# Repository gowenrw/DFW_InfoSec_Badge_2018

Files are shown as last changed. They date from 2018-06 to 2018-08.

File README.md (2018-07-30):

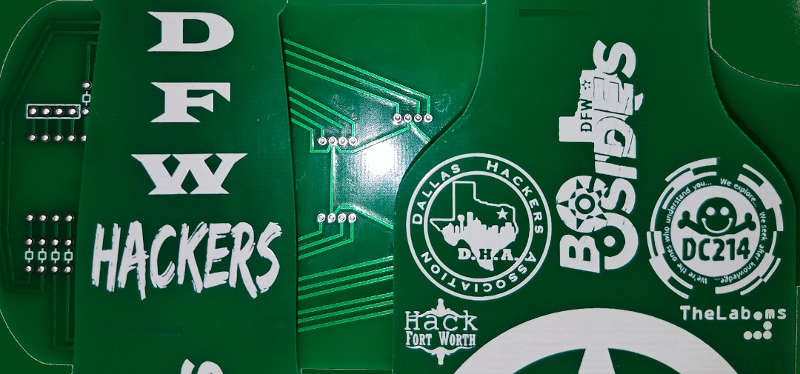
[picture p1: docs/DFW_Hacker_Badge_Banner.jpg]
Hero Image


# DFW Hacker Badge

Welcome to the DFW Hacker Badge website.

This is where you will find all the details of our badge including the components in the kit, assembly instructions, and code.

Please allow me to be your guide.

-- [@alt_bier](https://twitter.com/alt_bier)

## DIY Badge... Say What?!?

Yes, you read it correctly.  This is a DIY badge.  Some assembly required.
We will not be selling assembled badges.

This badge was designed to be an educational badge.

Building the badge from our kit will help teach people basic Electronics and Soldering skills
as well as Arduino Hardware Development and Programming skills.

To assist those without these skills I will link to online training that I created later on this page.
I will also be doing in person badge building classes at the following locations:

* A local DFW area badge building class will be scheduled in mid July.
    * This class has been scheduled for Tuesday July 17th at 6:30PM.
    * Sign up for the class via this Meetup link: [DFW Hacker Badge Building](https://www.meetup.com/TheLab-ms/events/252229891/)
* At BSidesLV I will find a nice corner to hang out and sell badges and answer any questions
    * I will post here and to twitter where and when that is once I know.
* At DEFCON I will be in the Hardware Hacking Village to sell badges and give building assistance
    * I'll post here and to twitter when I'll be at the HHV once my schedule is sorted.
* At BSidesDFW in Nov I will be running the Hardware Hacking Village featuring badge building.
    * This will be a much more comprehensive set of classes covering PCB design through badge assembly.
    * Details will be posted to BSidesDFW communications closer to that event.

## Show Me The Money!

All funds raised by the sale of this badge after production costs will go to
[BSidesDFW](http://www.bsidesdfw.com/) which is a 501c3 non-profit.

These badges will be sold at [BSidesLV](https://www.bsideslv.org/) and [DEFCON](https://defcon.org/).

The full kit will cost **$40.00** and just the PCB with no components will cost **$20.00** .

Early bird adopters (DFW area sales prior to hacker summer camp) will get them for half off.

A complete financial overview of the project including production costs is stored in this repo
and is available [HERE](https://github.com/gowenrw/DFW_InfoSec_Badge_2018/blob/master/Financials.md) for review.

## What's In The Kit?

The badge kit will contain everything you see pictured below.

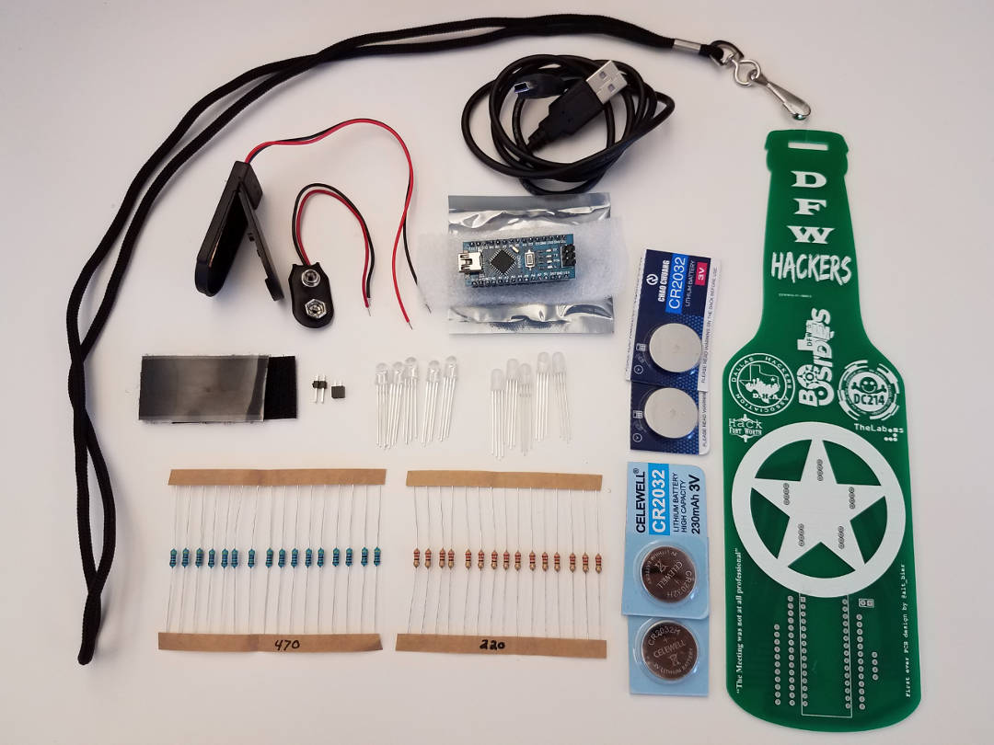
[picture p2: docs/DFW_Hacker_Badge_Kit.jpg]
Badge Kit Image


Here is a complete list of the items included in the kit:

* 1x Beer Bottle Shaped PCB
* 1x Lanyard (black or green)
* 1x Arduino Nano (pre-loaded with badge code)
* 1x USB A to Mini-B Cable (for programming the Arduino)
* 5x RGB LEDs 5mm 4pin diffused (recommended LEDs)
* 5x RGB LEDs 5mm 4pin clear (optional LEDs to replace above for clear aesthetic)
* 15x 470 ohm resistors (recommended resistors)
* 15x 220 ohm resistors (optional to replace above for brighter LEDs and shorter battery life)
* 1x 1x2 male header pins (optional use for power pins)
* 1x 1x2 female header pins (optional use for power pins)
* 1x 6v 2xCR2032 coin cell battery holder (recommended battery holder)
* 4x CR2032 coin cell batteries (two sets for above)
* 1x 9v battery holder (optional replacement for above, 9v battery not included)
* 1 inch of Velcro adhesive strips (for battery holder attachment)

## Assembly Instructions

__[Click Here for detailed assembly instructions with pictures](./assembly.html)__

Here is a basic list of what you need to do:

* Add the Arduino to the PCB
    * Plug the Arduino into the front of the PCB by pushing its header pins into the appropriate holes
    * It should be a tight fit but make sure the Arduino is pushed all the way down
    * Flip the PCB over so that the header pins poking through are clearly visible
    * Solder each pin to the pad surrounding the hole on the PCB
    * Inspect each solder joint and correct as needed
    * On the backside of the PCB cut the header pins off just above the solder joint
* Add the resistors to the PCB
    * Unlike the header pins on the Arduino, the resistors have soft leads that are easy to bend
    * Bend each resistor into a U shape (with the resistor at the bottom of the U)
    * Push each resistors leads into appropriate holes in the front of the PCB
    * This will be a very loose fit so take care to hold the resistor in place as you flip the PCB over
    * On the back of the PCB bend the leads outward at 45 to 90 degrees to hold the resistor in place
    * Solder each lead of the resistor to the pad surrounding the hole on the PCB
    * Inspect each solder joint and correct as needed
    * On the backside of the PCB cut the leads off just above the solder joint
* Add the LEDs to the PCB
    * Plug each LED into the front of the PCB by pushing its header pins into the appropriate holes
    * Make sure you orient the LED correctly so the common cathode pin goes into the correct hole.
        * Each LED will have one pin longer than the others, this is the common cathode pin
        * You can tell the common cathode hole on the PCB by looking at the traces on the back
        * The common cathode holes for all five LEDs will be connected together by traces
    * It'll be a tight fit but make sure the LED is pushed all the way down to the pin stops
    * Flip the PCB over so that the LED pins poking through are clearly visible
    * Solder each pin to the pad surrounding the hole on the PCB
    * Inspect each solder joint and correct as needed
    * On the backside of the PCB cut the pins off just above the solder joint
* Add the battery connector to the PCB
    * Plug the bare ends of the lead wires for the battery connector into the power holes in the PCB
    * Secure the wires in place so that the bare wires do not move in the PCB holes
    * Solder each wire to the pad surrounding the hole on the PCB
    * Inspect each solder joint and correct as needed
    * Cut any excess wire off just beyond the solder joint
* Insert batteries and Turn it On     

If you are new to soldering you should review this training material I put together:
[Electronics Soldering Basics](http://solder.altbier.us/)

## Arduino Code for the Badge

The Arduino that came in the kit should have been loaded with code that will work with your badge.
This code walks different colors around the star of the badge by turning on and off LEDs.

This code is available here:
[DFW-InfoSec-Badge-Color_Walk_low_power](https://raw.githubusercontent.com/gowenrw/DFW_InfoSec_Badge_2018/master/DFW-InfoSec-Badge-Color_Walk_low_power/DFW-InfoSec-Badge-Color_Walk_low_power.ino)

There is a version of this code that lights multiple LEDs at once when walking color around the badge.
This version uses more power which is why it was not loaded by default.

This code is available here:
[DFW-InfoSec-Badge-Color_Walk](https://raw.githubusercontent.com/gowenrw/DFW_InfoSec_Badge_2018/master/DFW-InfoSec-Badge-Color_Walk/DFW-InfoSec-Badge-Color_Walk.ino)

There are more code examples in the github repository that you may want to check out.

If you are new to the Arduino you should review this training material I put together:
[Arduino for Beginners](http://arduino.altbier.us/)

---

# Badge Details

## Story

For a couple of years now several of us at the various DFW InfoSec groups have
talked about creating a badge to wear and trade at the cons.

However, it always seemed to hit the back burner until it was too late to get made in time.

This year was no different.  But, I really didn't want to let it go this time.

So, with no PCB creation experience and severe time limitation I set out on the quest for the badge.

## Timeline and Simplicity

I figured in order to make the timeline I would have to keep the board simple.

Given my lack of PCB experience, I decided to fall back on my hardware development board experience.

This allowed for the creation of a board that is just traces, pads, holes, and silkscreen art... simple.

All the components which include an Arduino Nano with some RGB LEDs will need to be added in post.

## Fritzing PCB Design

I decided to use Fritzing for the PCB design since I previously used its breadboard and
schematic features when working with various hardware development platforms.

While I realize that it is not the most robust program for working with PCBs, it does
support exporting Gerber files for manufacturing.

So, my prior knowledge and the timeline dictated its use over learning a new tool.

## Custom PCB Board Shape and Silkscreen

In order to make a custom shaped PCB with silkscreen art Fritzing requires vector graphics in SVG format.  
The SVG needs two group ID's, one for the board shape and one for the silkscreen art.
Here are what those look like:
```
<g id="board">
...
<g id="silkscreen">
```

So, I created an Illustrator image with these vectors and exported it to SVG.

Then I created a PCB in Fritzing and loaded the SVG image.
This is where I ran into a problem.  Fritzing requires width and height be specified.
This is regardless of any viewBox that may be present.
Illustrator exports with a viewBox only, so I needed to manually add the width and height
matching the viewBox values.

Here is what this looks like after my edit:
```
<svg version="1.2" baseProfile="tiny" xmlns="http://www.w3.org/2000/svg"
xmlns:xlink="http://www.w3.org/1999/xlink" x="0px"  y="0px"
width="248" height="832" viewBox="0 0 248 832" xml:space="preserve">
```

## The Circuit

I knew that I wanted to use an Arduino and some LEDs to keep it simple.
So, I came up with a design using an Arduino Nano and five RGB LEDs.

The trick to creating the circuit on the PCB was that I wanted to keep
the board to a single copper layer.
This means that no two traces can cross paths.

This did add some limitations to my design specifically in potential LED placement
as well as in the use of digital and analog pins.

But, these all worked out and I was able to create a circuit design that will
work as a single layer on a PCB.

## Testing The Circuit

Once I had the circuit designed I needed to make sure it would work.

So, I pulled out the boxes of breadboards, jumpers, and components.

I build the circuit exactly the way it was laid out on Fritzing.

I then wrote a quick Arduino script to test all five RGB LED functionality via the circuit.

It's some simple sloppy code, but got the job done... the circuit works.

##### Code Limitation

Because of the specific pins I had to use to each LED in order to keep it single layer, one
of the limitations is that most the LEDs do not have all three colors on analog or pwm pins.

These are the pins that allow you to do ```analogWrite``` to fade an LED on or off.

Since only ```digitalWrite``` will need to be used for consistency this means the RGB LED colors will be
on or off when they are set to ```HIGH``` or ```LOW``` and cannot be faded.
So, where you can turn on red and blue to make purple, you cannot fade them to get pink or lavender.

## Gerber Files

What allowed me to use Fritzing at all for PCB creation was its ability to export Gerber files for manufacturing.

These are the files and format that most of the PCB manufacturing sites require to build your design.

The Gerber files that are shown here are exports from Fritzing that were sent to be produced.

I've included them here so that if the board turns out good and someone wants to make more they can do so
without having to do any of the design work.  Simply send the manufacturer the Gerber files.

##### Layer and Color Limitation

While Fritzing will output Gerber files it does so with some limitations.

The first limitation is regarding the Solder Mask layers and the fact that Fritzing ignores any such layers
provided by your Custom PCB SVG file.  It will always use Green solder mask that covers your board front and back.

While some PCB manufacturers allow you to change the color of the solder mask during ordering, others do not.

The second limitation is regarding the Silkscreen layers and the fact that Fritzing always changes the color to white.

While some PCB manufacturers allow you to change the silkscreen color during ordering, others do not.

At first I though the solder mask color would be a big issue for my beer bottle shaped board.
But, then I found that most the cheap PCB places do not offer Brown solder mask and those that do charge a lot for it.
I was planning on the white silkscreen anyway, so with a green bottle we will be rocking Rolling Rock badges.  LOL

## Summary

This crazy badge creation bug got in my head at a DHA meeting on a Wednesday night and seven days later
I had a badge PCB prototype run on order and presented it at the DC214 meeting.

One week from start to finish is not bad considering I've never done this before.

I just hope it turns out good and that people receiving the badges are not too mad about all the soldering needed to make it functional.

-- [@alt_bier](https://twitter.com/alt_bier)

---

# Badge Hacks

So, just twenty four hours after the first badge sale it was hacked!

I will tag any badge hacks I am made aware of to the end of this page.

## Neopixel PL9823 Hack (First hack of this badge!)

[TheLab.ms](https://thelab.ms) did an awesome job hacking the badge by replacing the dumb RGB LEDs
with smart Neopixel type LEDS and the result looks awesome.

Here is an awesome write up on this hack:
[TheLab.ms PL9823 Badge Hack](https://github.com/gowenrw/DFW_InfoSec_Badge_2018/raw/master/hacks/PL9823_DemoCode/DFW_Hackers_Badge-HACKED.pdf)

The code for this hack is here:
[PL9823_DemoCode](https://github.com/gowenrw/DFW_InfoSec_Badge_2018/tree/master/hacks/PL9823_DemoCode)

This small video shows this hack in action:
[TheLab.ms_Neopixel_Badge_Hack](https://raw.githubusercontent.com/gowenrw/DFW_InfoSec_Badge_2018/master/hacks/PL9823_DemoCode/TheLab.ms_Neopixel_Badge_Hack.mp4)

## Add Sound Hack

Not to be outdone, I have also hacked the badge to add sound to it via a tiny speaker placed
in the center of the star which plays "Deep in the heart of Texas" to an LED light show.

The code for this hack is here:
[Add-Sound](https://github.com/gowenrw/DFW_InfoSec_Badge_2018/tree/master/hacks/add-sound)

A small video of this hack in action is available here:
[DFW_Hacker_Badge_Add_Sound_Hack](https://youtu.be/RLlT0CuagGU)

## WiFighter Hack

In one of the best hacks I've seen yet, [@Ridgeback111](https://twitter.com/Ridgeback111) has
created a WiFi scanner/counter hack of our badge using ESP32 and CiruitPython Express.

The code for this hack is here:
[WiFighter](https://github.com/gowenrw/DFW_InfoSec_Badge_2018/tree/master/hacks/WiFighter)

Here is a small video of this hack in action:
[WiFighter_Badge_Hack](https://youtu.be/AukL9QIAfeE)

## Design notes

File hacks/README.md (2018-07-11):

# Hacks

This section contains a list of the known hacks done to this badge.

Weather it is using different components or adding functionality,
any hack I find out about will be listed.
I expect quite a few entries here as people get access to the badges.

Each hack will be in its own directory with any information, code,
schematics, etc. related to the hack.

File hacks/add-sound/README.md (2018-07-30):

# Add Sound

This is a quick little hack to add some sound to the badge.

The idea is fairly simple: add a tiny 8 ohm speaker to the center of the star on the badge
connected to unused Arduino pins and program it to play sounds in sync with LED lights.

The idea of playing sounds without the need for a sound file came from this project:
https://www.arduino.cc/en/Tutorial/toneMelody

I got it to play "Deep in the heart of Texas" on a tiny speaker plugged into A5 and GND.

The code is up to date now.

A small video of this hack in action is available here:
[DFW_Hacker_Badge_Add_Sound_Hack](https://youtu.be/RLlT0CuagGU)

Enjoy.

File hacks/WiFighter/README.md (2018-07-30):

# WiFighter

This hack was shared with us by [@Ridgeback111](https://twitter.com/Ridgeback111)

This hack will turn your badge into a WiFi scanner / counter using ESP32 and CiruitPython Express.

Here is a small video of this hack in action on the badge:
[WiFighter_Badge_Hack](https://youtu.be/AukL9QIAfeE)

Here is another video of it working before being added to the badge:
[WiFighter POC](https://youtu.be/-_xaSA5cCK4)

Here are some photos of the hack assembled on the badge:
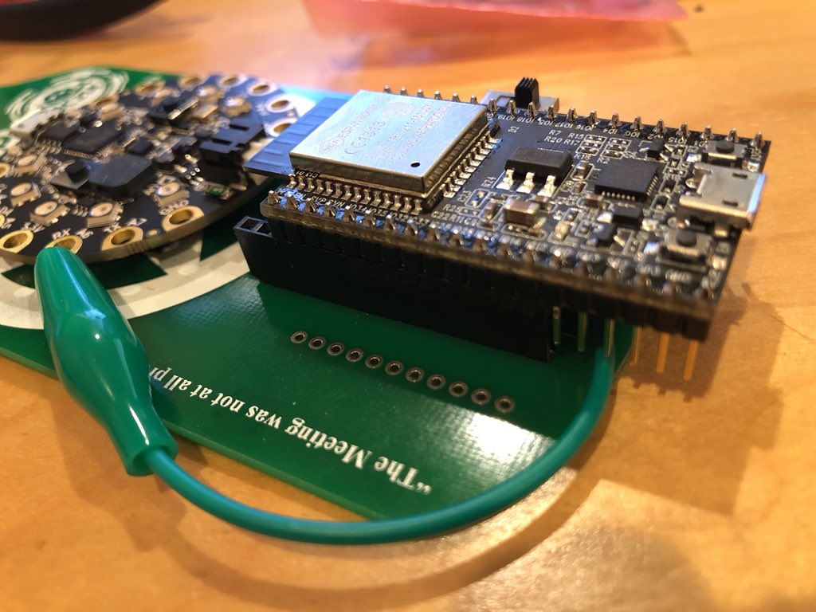
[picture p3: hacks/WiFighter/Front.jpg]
Front

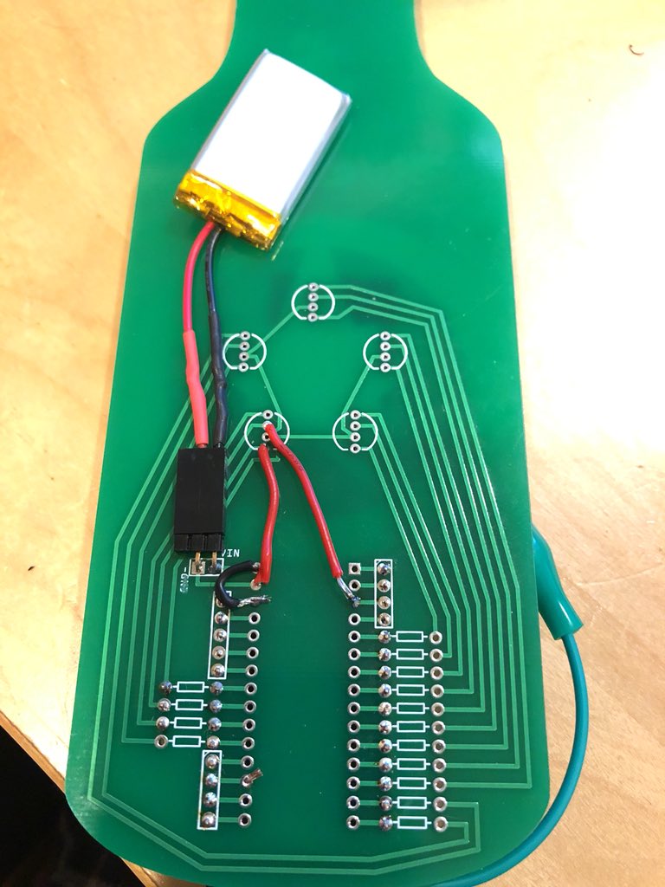
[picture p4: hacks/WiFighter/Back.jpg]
Back


## The hack explained

The two devices used are an ESP32 DevKitC and a Circuit Python Express.
The ESP32 has micropython installed and the CPX obviously runs CircuitPython.

The switch on the bottom right is the power switch.

The green cable with the alligator lead is the serial line sending two bytes 00-99.

On the back is a LiIonPoly battery split to both devices.
The Vin is routed though the switch.

The existing pin holes and some traces were used for routing.

The wider set of pin rows was a perfect match for the width of the ESP32.

CPX code goes in main.py on the onboard flash.  
Here is the code used for [main.py](https://github.com/gowenrw/DFW_InfoSec_Badge_2018/blob/master/hacks/WiFighter/main.py)

ESP32 code uploads to boot.py in his flash.
Here is the code used for [boot.py](https://github.com/gowenrw/DFW_InfoSec_Badge_2018/blob/master/hacks/WiFighter/boot.py)

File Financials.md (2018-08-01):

# Financials

This is a list of the financial information associated with this badge.
This will include:

* A list of all the expenses and real costs associated with these.
    * Prototype board manufacture
    * Prototype test components
    * Production board manufacture
    * Production components
    * Production accessories (lanyard, etc.)
* A unit cost breakdown
    * Cost per board without components
    * Cost per board with components
* Price points and potential revenue for BSidesDFW (the non-profit receiving the money after expenses).
    * Price per board without components
    * Price per board with components

Note that all of these numbers are based off an assumption that we will be producing
300 PCBs, 150 of which will include all the components.
Update: Given the local demand for the kits had to source additional components to bring the totals
up to 180 kits with all the components.

## Expenses

Here is a list of actual expenses ~~and projected expenses~~ by category:

* Prototype board manufacture
    * Prototype PCB boards
        * QTY 10 From [https://jlcpcb.com/](https://jlcpcb.com/) cost $40.84
* Prototype test components
    * Various components to test with including three types of RGB LED's, resistors, header pins, 9V battery connectors, etc.
        * QTY Varies From [https://lcsc.com/](https://lcsc.com/) cost $80.52 shipping $38.00
    * Different Resistors from above and more Solder
        * QTY Varies From [https://www.amazon.com/](https://www.amazon.com/) cost $38.13
    * 9V Batteries
        * QTY 8 From [https://www.amazon.com/](https://www.amazon.com/) cost $9.99
    * Double CR2032 Battery Holder with On/Off switch for testing (to replace the 9V design)
        * QTY 4 From [https://www.amazon.com/](https://www.amazon.com/) cost $6.99
    * CR2032 Batteries
        * QTY 10 From [https://www.amazon.com/](https://www.amazon.com/) cost $6.69
    * CR2016 Batteries
        * QTY 10 From [https://www.amazon.com/](https://www.amazon.com/) cost $6.99
    * Arduino Nano V3 boards
        * QTY 20 From [https://www.ebay.com](https://www.ebay.com) cost $59.98 shipping $6.00
    * USB Cable A Male to Mini-B Male (for programming Arduino's)
        * QTY 20 From [https://www.amazon.com/](https://www.amazon.com/) cost $26.98
* Production board manufacture
    * Production PCB boards
        * QTY 300 From From [https://jlcpcb.com/](https://jlcpcb.com/) cost $599.42
        * Shipping on above cost $240.78
* Production components
    * Arduino Nano V3 boards
        * QTY 10 From [https://www.ebay.com](https://www.ebay.com) cost $27.50 shipping $4.00
        * QTY 10 From [https://www.ebay.com](https://www.ebay.com) cost $27.50 (free shipping)
    * USB Cable A Male to Mini-B Male (for programming Arduino's)
        * QTY 10 From [https://www.amazon.com/](https://www.amazon.com/) cost $12.99
    * Arduino Nano V3 boards (CH340 USB chip) INCLUDING USB Cable A Male to Mini-B Male
        * QTY 100 From [https://www.alibaba.com/](https://www.alibaba.com/) cost $286.00 shipping $40.00
        * QTY 10 From [https://www.ebay.com](https://www.ebay.com) cost $33.80 (free shipping)
        * QTY 20 From [https://www.ebay.com](https://www.ebay.com) cost $68.36 shipping $11.96
        * QTY 10 From [https://www.ebay.com](https://www.ebay.com) cost $34.18 shipping $5.98
        * QTY 20 From [https://www.ebay.com](https://www.ebay.com) cost $68.36 shipping $11.96
        * QTY 10 From [https://www.ebay.com](https://www.ebay.com) cost $34.18 shipping $5.98        
    * RGB LEDs and Resistors
        * QTY 600 LEDs and resistors and headers From [https://lcsc.com/](https://lcsc.com/) cost inc. shipping $101.01
        * QTY 500 LEDs From [https://www.alibaba.com/](https://www.alibaba.com/) cost inc. shipping $53.20
        * QTY 300 LEDs with Resistors From [https://www.amazon.com/](https://www.amazon.com/) cost $38.18
        * QTY 1k Resistors From [https://www.amazon.com/](https://www.amazon.com/) cost $12.10
        * QTY 300 LEDs From [https://www.amazon.com/](https://www.amazon.com/) cost $26.97
    * Battery Holder - 6v 2x3V CR2032 with on/off Switch Lead Wire Type
        * QTY 30 (2x15 pack) From [https://www.amazon.com/](https://www.amazon.com/) cost $47.96
        * QTY 100 (10x10 pack)  From [https://www.amazon.com/](https://www.amazon.com/) cost $38.90 - May not arrive in time, Need to order more just in case
        * QTY 30 (2x15 pack) From [https://www.amazon.com/](https://www.amazon.com/) cost $47.96
        * QTY 10 From [https://www.amazon.com/](https://www.amazon.com/) cost $13.99
        * QTY 30 (2x15 pack) From [https://www.amazon.com/](https://www.amazon.com/) cost $38.97
    * Battery Holder - 9v Lead Wire Type
        * QTY 100 From [https://www.amazon.com/](https://www.amazon.com/) cost $12.00
    * Batteries - CR2032 coin cells (4x per kit plus 100 spares / replacements = 820 needed)
        * QTY 100 (20x5 pack)  From [https://www.amazon.com/](https://www.amazon.com/) cost $23.99
        * QTY 100 (4x25 pack)  From [https://www.amazon.com/](https://www.amazon.com/) cost $18.99
        * QTY 100 (20x5 pack)  From [https://www.amazon.com/](https://www.amazon.com/) cost $23.97
        * QTY 100 (20x5 pack Sony)  From [https://www.ebay.com](https://www.ebay.com) cost $53.97 Free Shipping
        * QTY 100 (20x5 pack)  From [https://www.ebay.com](https://www.ebay.com) cost $46.59 Free Shipping
        * QTY 100 (20x5 pack Sony)  From [https://www.ebay.com](https://www.ebay.com) cost $53.97 Free Shipping
        * QTY 100 (20x5 pack Energizer)  From [https://www.ebay.com](https://www.ebay.com) cost $65.68 Free Shipping
        * QTY 100 (20x5 pack)  From [https://www.ebay.com](https://www.ebay.com) cost $32.84 Free Shipping
* Production accessories (lanyard, etc.)
    * Lanyard, simple satin with swivel J-hook
        * QTY 100 BLACK From [https://www.amazon.com/](https://www.amazon.com/) cost $20.99
        * QTY 100 GREEN From [https://www.amazon.com/](https://www.amazon.com/) cost $16.99
        * QTY 100 BLACK From [https://www.amazon.com/](https://www.amazon.com/) cost $20.99
    * Anti-static Resealable Bag for components
        * QTY 100 From [https://www.amazon.com/](https://www.amazon.com/) cost $11.00
        * QTY 100 From [https://www.amazon.com/](https://www.amazon.com/) cost $18.68
    * Rubber Bands Wide for securing component bag to PCB for distribution
        * QTY 3 Bags From [https://www.amazon.com/](https://www.amazon.com/) cost $11.99
    * Self Adhesive Velcro for battery attachment
        * QTY 1inx15ft From [https://www.amazon.com/](https://www.amazon.com/) cost $7.89
        * QTY 1inx30ft From [https://www.amazon.com/](https://www.amazon.com/) cost $15.96
    * Shipping to Vegas
        * Shipping Supplies - Bubble Wrap and Box Tape from Home Depot cost $27.82
        * Shipping Fees - USPS 4 large flat rate boxes with extra insurance cost $93.60

#### Expense Table

| Category | Actual | Projected | Total |
| --- |:---:|:---:|:---:|
| Prototype board manufacture  | $40.84 | $0.00 | $40.84 |
| Prototype test components | $280.27 | $0.00 | $280.27 |
| Production board manufacture | $840.20 | $0.00 | $840.20 |
| Production components | $1423.99  | $0.00 | $1423.99  |
| Production accessories | $245.91 | $0.00 | $245.91 |
| Totals | $2831.21  | $0.00 | $2831.21  |

## Unit Cost Breakdown

Notes on the unit cost breakdown:
* Expenses from above will be divided out across the boards for the unit cost breakdown
* Total PCB count of 300
* Total kits (components to be paired with PCBs above) of ~~150~~ 180
    * NOTE: Based on the increased number of DFW area kit sales I needed to source additional kits
* Not counting the 10 prototype boards since they will get messed up in testing
* Including prototype costs in the overall costs for the production unit breakdown

#### Unit Cost Table

| Category | Total | Qty | Unit Cost |
| --- |:---:|:---:|:---:|
| PCB and Lanyard Only | $703.61 | 130 | $5.41 |
| Kit including PCB, Lanyard, and Components | $2127.60  | 180 | $11.82 |

How these numbers were derived:
* PCB/Lanyard Cost is (Prototype board manufacture /2) + (Prototype test components /2) + (Production board manufacture /2) + (Production accessories /2)
* Kit Cost is (Prototype board manufacture /2) + (Prototype test components /2) + (Production board manufacture /2) + (Production accessories /2) + (Production components)

## Price Points

Beyond recovering manufacture costs we want to raise money for the non-profit BSidesDFW.
With that in mind these are the current price points (subject to change):

#### Early Bird Adopters (DFW Area Purchases)

| Category | Price | Avail Qty | Potential Non-Profit Revenue  |
| --- |:-----:|:---:|:---:|
| PCB and Lanyard Only | $10 | 40 | $400.00 - $216.40 = $183.60 |
| Kit including PCB, Lanyard, and Components | $20 | 90 | $1800.00 - $1063.80 = $736.20 |

#### Hacker Summer Camp Prices

| Category | Price | Avail Qty | Potential Non-Profit Revenue |
| --- |:-----:|:---:|:---:|
| PCB and Lanyard Only | $20 | 80 | $1600.00 - $432.80 = $1167.20  |
| Kit including PCB, Lanyard, and Components | $40 | 90 | $3600.00 - $1063.80 = $2536.20 |

Our original goal was to raise $5k for the non-profit BSidesDFW after expenses.
These price points will get us close to that goal.  
Specifically they should bring about $4620 to support BSidesDFW if all sell as planned.

## Updates

All of the Actual costs are in place now.

Costs came in higher than originally planned due to switching to a coin cell battery design
instead of 9V and having to source additional parts to make more kits.

Will track all sales here after the Vegas conferences are over.

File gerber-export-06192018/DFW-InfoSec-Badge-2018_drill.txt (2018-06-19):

; NON-PLATED HOLES START AT T1
; THROUGH (PLATED) HOLES START AT T100
M48
INCH
T100C0.036000
T101C0.025000
T102C0.035000
T103C0.038000
%
T100
X017026Y008685
X017026Y003685
X011026Y006685
X017026Y009685
X017026Y014685
X011026Y008685
X017026Y010685
X011026Y003685
X011026Y017685
X011026Y009685
X011026Y010685
X017026Y016685
X017026Y004685
X011026Y012685
X011026Y015685
X017026Y017685
X017026Y015685
X011026Y013685
X017026Y011685
X017026Y012685
X017026Y005685
X017026Y006685
X011026Y007685
X011026Y011685
X011026Y014685
X011026Y016685
X011026Y004685
X017026Y007685
X017026Y013685
X011026Y005685
T101
X018626Y033659
X011026Y026285
X011026Y025497
X011026Y027071
X016826Y026285
X014026Y037459
X009026Y031297
X014026Y035885
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

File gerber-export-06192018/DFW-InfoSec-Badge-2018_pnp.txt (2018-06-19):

*Pick And Place List
*Company=
*Author=
*eMail=
*
*Project=DFW-InfoSec-Badge-2018
*Date=17:46:23
*CreatedBy=Fritzing 0.9.3b.04.19.5c895d327c44a3114e5fcc9d8260daf0cbb52806
*
*
*Coordinates in mm, always center of component
*Origin 0/0=Lower left corner of PCB
*Rotation in degree (0-360, math. pos.)
*
*No;Value;Package;X;Y;Rotation;Side;Name
1;150;THT;52.1377;-22.0601;0;Bottom;R6
2;150;THT;19.6257;-24.6001;180;Bottom;R8
3;;5 mm [THT];35.6278;-92.0704;90;Bottom;LED4
4;;THT;23.4357;-41.1101;0;Bottom;J2
5;150;THT;19.6257;-9.36007;180;Bottom;R14
6;150;THT;19.6257;-29.6801;180;Bottom;R1
7;9V;;51.1217;-44.9201;90;Bottom;VCC1
8;150;THT;19.6257;-11.9001;180;Bottom;R15
9;;5 mm [THT];42.7398;-67.6864;90;Bottom;LED2
10;;THT;48.3277;-13.1701;0;Bottom;J3
11;150;THT;52.1377;-27.1401;0;Bottom;R4
12;150;THT;19.6257;-16.9801;180;Bottom;R11
13;150;THT;19.6257;-32.2201;180;Bottom;R2
14;;5 mm [THT];28.0078;-67.6864;90;Bottom;LED1
15;;;48.1616;-46.9278;0;Bottom;TXT1
16;150;THT;19.6257;-19.5201;180;Bottom;R10
17;150;THT;19.6257;-22.0601;180;Bottom;R9
18;;THT;48.3277;-34.7601;0;Bottom;J4
19;;5 mm [THT];47.3118;-82.4184;90;Bottom;LED5
20;150;THT;19.6257;-14.4401;180;Bottom;R12
21;;;35.6277;-27.1316;0;Bottom;Part1
22;150;THT;19.6257;-27.1401;180;Bottom;R7
23;;;54.5859;-42.9434;-90;Bottom;TXT1
24;150;THT;52.1377;-24.6001;0;Bottom;R5
25;150;THT;52.1377;-19.5201;0;Bottom;R13
26;;5 mm [THT];22.9278;-82.4184;90;Bottom;LED3
27;150;THT;19.6257;-34.7601;180;Bottom;R3

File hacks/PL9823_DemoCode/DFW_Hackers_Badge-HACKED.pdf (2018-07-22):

# Hacking the DFW Hackers Badge

This hack has been brought to you by Gregory A. Miller of TheLab.ms

## Acknowledgement

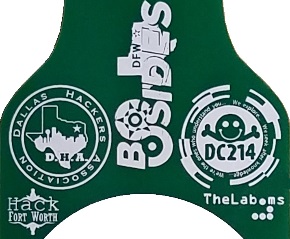
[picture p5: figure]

I first wish to acknowledge the work of Richard Gowen and all the excellent work and support he has selflessly provided in the form of promotion, mentorship and momentum boosts for the fine organizations so named on the face of the DFW Hackers Badge. TheLab.ms is but one of the organizations in which he has donated time and money to and I think I speak for all membership of TheLab.ms, we appreciate everything that he contributes to its continued success.

## Objective

There are four objectives:
1. Use a larger smart LED for a bolder appearance and more visual options.
2. Be able to reverse configure the badge using the original RGB LEDs and quickly switch between the two configurations without the need for soldering.
3. Have a single code base for all the above.
4. Everything should be reusable. No major components are permanent or altered.

## Engineering Considerations

The first step was to Identify the pins used on the Arduino and determine if the redesign was even possible. The leads were traced from the RGB LEDs back to each corresponding pin on the Arduino and created a diagram of the layout to reference during future revisions.

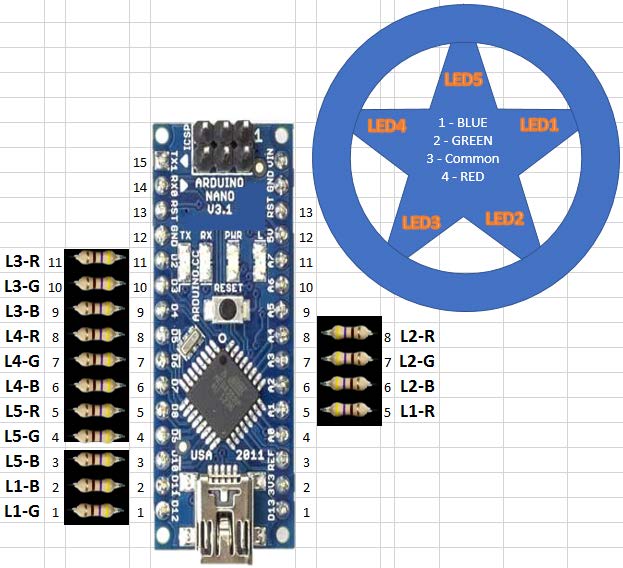
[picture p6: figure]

The project calls for a common cathode (common ground) RGB LED device. For the ease of identifying the pins the LEDs were numbered on the star pattern as shown above. The LED connections to the PCB are numbered from 1-4 to support the following functions:
1. BLUE
2. GREEN
3. GROUND
4. RED
Thus, as you read the labels surrounding the Arduino image, L1-R is LED #1 and the RED lead, Pin #4, where L2-B is LED #2 and the BLUE lead, Pin #1.
These labels are not useful in the original configuration build as all the hard work was completed by Richard and the only thing necessary to do was plug it in and turn it on… All of this pre-work came in handy on the redesign process to help identify how the LEDs would be tied together.

## Build Process

Nearly Original Build
In the above drawing, you see three black rectangles surrounding some resistors. These black rectangles represent sockets that hold resistors which are needed in the build. This was done to stay true to the list of objectives. In fact, everything was socketed in such a way the devices on the PCB could be quickly and easily removed and replaced if needed.
The Arduino has an odd number of pins so a slightly larger socket was custom cut and adapted for use. A standard 2.54mm pitch pin header strip was cut to length to fit the holes on both sides of the Arduino. The LED sockets began life as a 40 pin, 2mm pitch, header strip which was cut down to size and edges cleaned up before soldered into place.

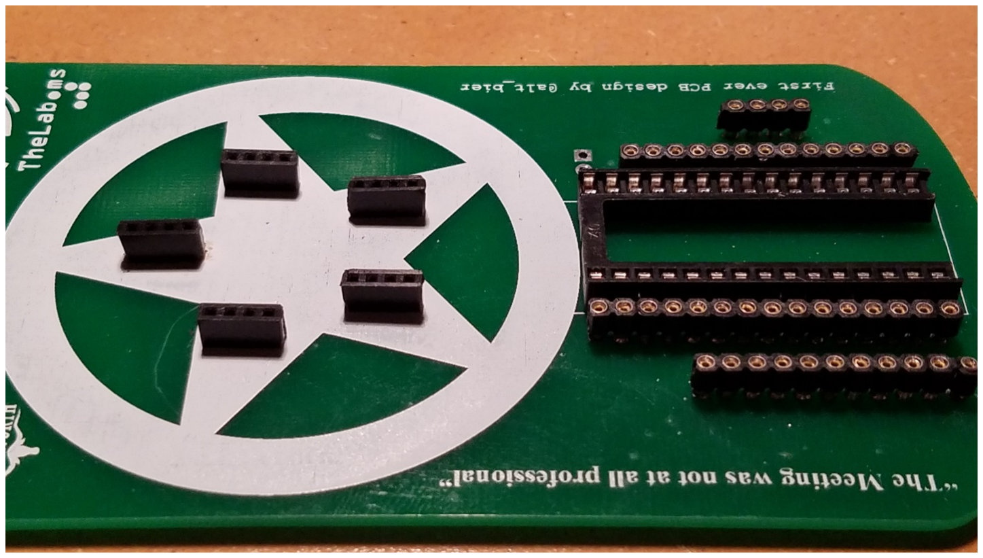
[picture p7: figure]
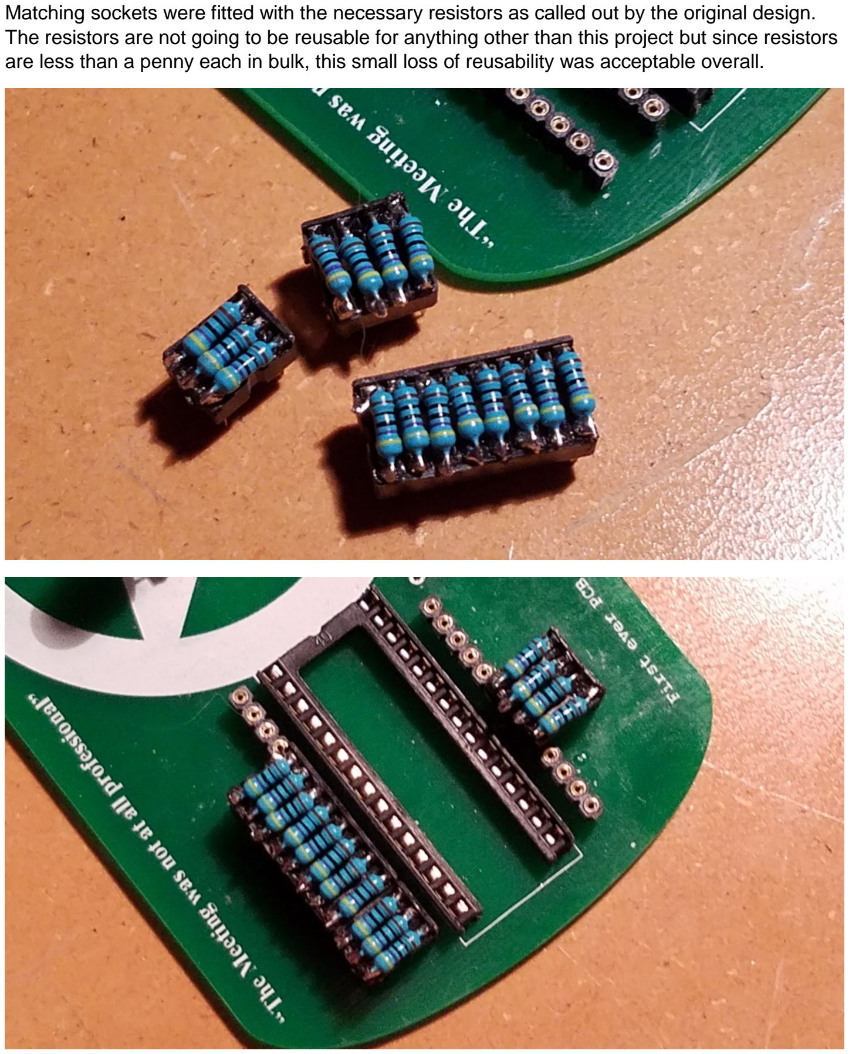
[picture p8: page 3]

Matching sockets were fitted with the necessary resistors as called out by the original design. The resistors are not going to be reusable for anything other than this project but since resistors are less than a penny each in bulk, this small loss of reusability was acceptable overall.

The RGB LEDs come with staggered leads which need to be all cut to a similar length so they can be inserted into the socket in a uniform fashion. Don’t cut too short it makes it hard to get them inserted but short enough so they are not getting their pins bent when bumped into. Approximately 0.5” long worked well. Also keep in mind the LEDs are polarized and need to maintain a specific orientation. The flat edge is how to know which direction to plug them in, after the leads are cut. The flat edge will always be oriented towards the bottom.

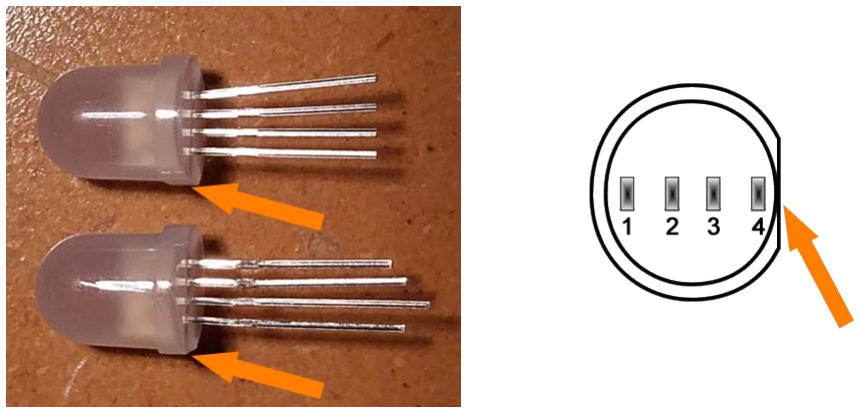
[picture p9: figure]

Everything was then plugged in according to the original project documentation and away it went. Now let’s improve on what we have.
Next Generation Build
After tracing the wiring connections in the previous build, it was determined that this project could be rewired to change its personality in a modular fashion thus keeping with the original objectives. Here is the revised wiring diagram:

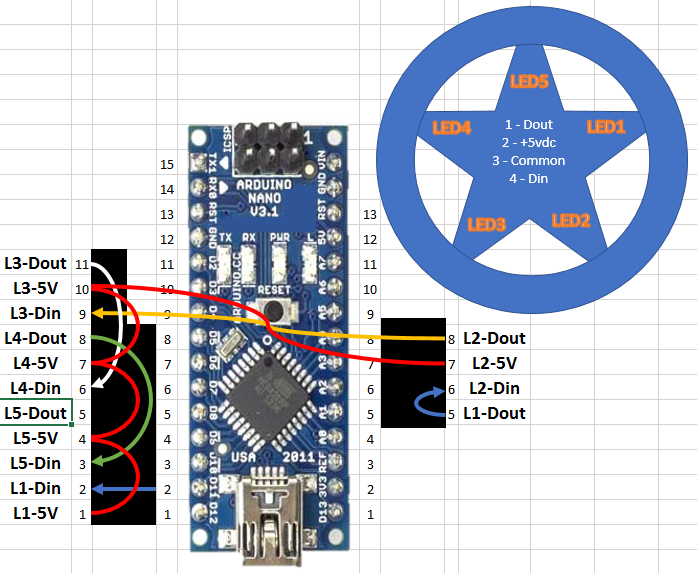
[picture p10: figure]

## PL9823 Pinouts

1. Data Out
2. +5vdc Vcc
3. GROUND
4. Data In
While this device looks like an RGB LED, it is wired and controlled very differently.

Since the PL9823 LEDs operate on a PWM serial link principle, the data in and data out pins were identified and the resistors, in the original build, were replaced with jumper wires soldered into sockets so the data paths retain my numbering definitions of LED1 → LED5
In the photo above, you can see there is an arrow on the data lines which notate the direction the serial data is flowing. I built the wiring modules (shown below) using a wire color to match.

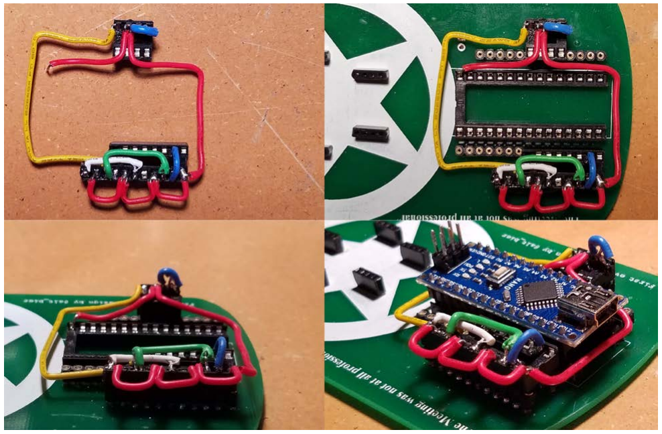
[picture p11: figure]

The PL9832 LEDs work similarly to the popular Adafruit NeoPixel and WS2812 devices but at a significantly lower per unit cost, at least lower at the time of purchase.

## Software Design

The goals behind the software was to have the ability to have a single codebase to drive the original RGB LEDs and the LP9823 devices. This would enable the change of desired functionality without the need to have a computer handy to reprogram the Arduino Nano.
The goal is to use the unused GPIO as a selector switch of sorts. Reading about current draw on the Arduino pins, it is determined that a direct link from a GPIO to ground or power would create a direct short and potentially zap the Arduino device nearly immediately. Shorting two GPIO pins together could also, in certain circumstances, cause the same short condition. This means a resistor must be used.
A safe way to do this is to build a custom M-F jumper wire that has a 10Kohm resister soldered in line with some tape or shrink tubing to protect it. This provides an easy way to choose between one of eight analog pins on the Nano without making any permanent modifications to the board.

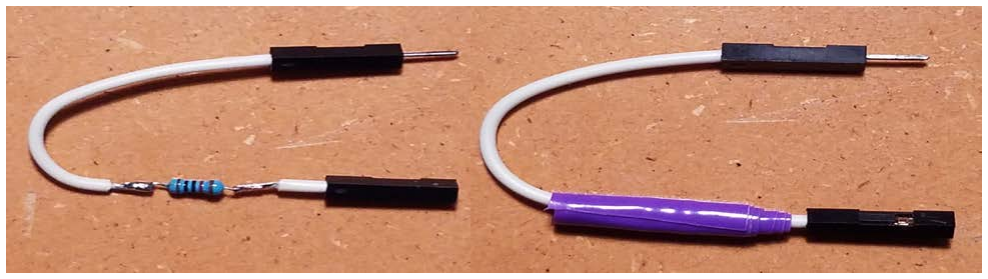
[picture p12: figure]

The customized jumper is used to make a demo selection by plugging the female end onto the Vcc pin of the ICSP port on the Nano and the other end into any of the available Analog pins exposed. The image below shows it plugged into the Analog A1 pin of the socket.

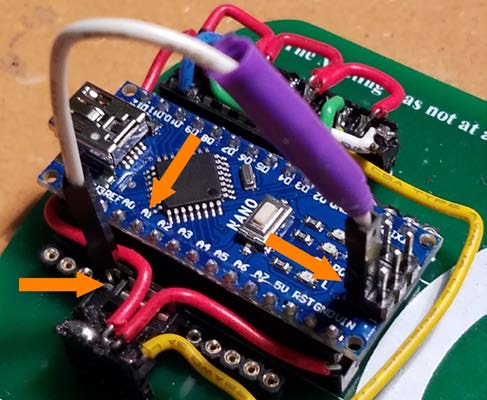
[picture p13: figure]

This connection only needs to be made when power is applied or when a reset is performed and then can be removed if desired. The code is designed to read the selection as it is setting everything up and then it does not read it again unless the Arduino is reset or power cycled. *** CAUTION :: This is a Live Vcc connection so be careful not to short anything out. *** Code Section actually starts here…
The Adafruit NeoPixel libraries were used in this demo code for simple implementation but you can use whatever libraries you want or simply write your own. I also started with the Example code named “strandtest”, which comes with the Adafruit NeoPixel library, as a foundation for creating several fast demos for this project. This example code is designed for use with pre-cut lengths of the NeoPixel strips but is easily modified for this application.
The hack project only has 5 PL9823 devices to work with so we do not have much to play with as far as eye candy demos are concerned (see Final Thoughts section) but here is how our code and demos work:
First step is to add the Adafruit NeoPixel libraries to your code:
// This sketch requires the Adafruit NeoPixel Library v1.1.6 or higher #include <Adafruit_NeoPixel.h>

// Depending on your device model and Mfr. the parameter in the following line can be either NEO_GRB or NEO_RGB.
// If the colors are all wrong, try switching this parameter. All it does is change the bit order on the colors output.
Adafruit_NeoPixel pixels = Adafruit_NeoPixel(DEVICECOUNT, PIN, NEO_RGB + NEO_KHZ800);
The remaining items are to define the pin to be used for the PWM output signal. It seem that a variable the number of device is silly but you can expand this from 5 to several hundred if desired.
// Which Arduino pin is the PWM Output? Nano options include 3,5,6,9,10,11 // PIN 5 was chosen by default to match the Hacked schematic.
#define PIN | 11

// This defines how many LED devices you have on the string.
#define DEVICECOUNT 5

// If you experience flicker or random flashes of color, increase this delay to make it go away.
int iDelay_ms = 500; // Time delay in miliseconds
There were minor tweaks to the original RGB code so it would be able to coexist with the Hack code. I only took out the original Setup() function and replaced the original Loop() function with a while() loop. The whole thing is then wrapped up in a function called OriginalBadgeCode(). In the following code blocks the RED code was removed, PURPLE was modified.

## void OriginalBadgeCode() {

//void setup() | // Original Setup function was commented out. The remaining
//{ | // initialization of vars was merged into calling function.
// Reminder of original code was unchanged.
…
Original Setup() code goes here in its entirety
…
//}

// Main Loop | // Original Main function was commented out. The remaining
//void loop() | // code of the loop was placed into a never ending while() // to emulate the original Main loop.

## while(1)

{
…
Original Setup() code goes here in its entirety …
}
}
The new Setup and Main functions control the actions of the Hacked Badge. In Setup there is a call to a function called ConfigurationSet() which determines which personality the badge should be operating as:
void ConfigurationSet() {
// Determine if the RGB configuration is active or the Hacked configuration. for(int a=0;a<8;a++){
// The Nano has 8 analog pins which can be used for selection testing. // Test each one and find one that has an output value of "1023" Serial.println(analogRead(a));
if(analogRead(a)==1023){
| iSelected = a;
| break;
}else {
| iSelected = 99;
}
}
}
Based on the value placed into the iSelected variable determines which personality the Main loop will begin executing:
Void loop() {
switch(iSelected) {
case 0:
demoBasic();
break;
case 1:
// This demos two different techniques for fading demoFade1(5);
demoFade2(5);
break;
case 2:
demoSpinningWheel();
break;
case 3:
demoRandomBlinky(500);
break;
case 4:
demoPatriotic();

break;
case 5:
demoFunColors(1000);
break;
case 6:
demoRandomColors(100);
break;
case 7:
// This selection runs all the demos in order demoBasic();
demoFade1(5);
demoFade2(5);
demoRandomBlinky(500);
demoPatriotic();
demoFunColors(1000);
demoRandomColors(100);
break;
default:
// This is only run if the badge is in RGB mode Serial.println("RGB Configuration"); OriginalBadgeCode();
break;
}
}

## Final Thoughts

You can easily extend this project with more PL9823 devices by using the L5-Dout pin to another Din on a 6th device or an entire string of devices. The Nano should be able to drive several hundred devices, given enough power to light them all.
This was an incredibly fun project. There are so many things that can be done to the badge beyond blinking lights and we will be exploring some additional ideas soon.

## Pitfalls & Lessons Learned

1. When soldering your socket to the PCB, use only enough solder to attach the socket to the via. The sockets I used had an open bottom so I had the unfavorable issue if solder filling the socket and thus decreasing the grip effect and depth of insertion. This caused my LEDs to not make a good circuit connection after getting jostled around a bit.
2. Use solid core wire so its rigid properties can be exploited in keeping the sockets in place during use.
3. The Arduino Nano cannot drive too much current and will fail catastrophically.
4. If odd and unexplainable things are happening, check for shorts and open connections.
5. The LEDs do not keep good connection in the sockets.
6. Do NOT tie the GPIO directly to Vcc or GND as this will cause a direct short and can cause the release of the magic smoke.
7. Batteries can get short circuited if not handled properly. =<

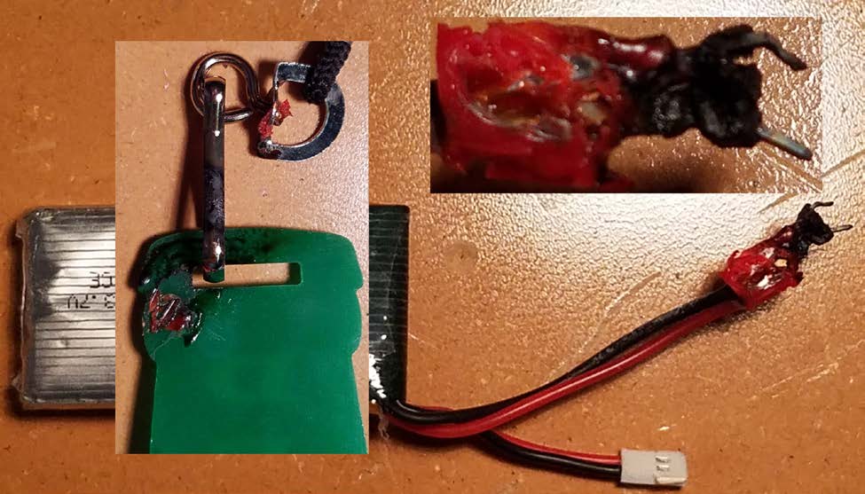
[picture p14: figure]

## References

Adafruit - NeoPixel Diffused 8mm Through-Hole LED (https://www.adafruit.com/product/1734)
NeoPixel is a trademark of Adafruit. You can get these directly from Adafruit as well as some distributors stock them as well.
Amazon.com - 8mm WS2812 Addressable LED – RGB (https://www.amazon.com/s?url=search-alias%3Daps&field-keywords=ws2812+8mm&rh=i%3Aaps%2Ck%3Aws2812+8mm)
Amazon.com – 8mm PL9823 Addressable LED – RGB (https://www.amazon.com/s?url=search-alias%3Daps&field-keywords=PL9823+8mm&rh=i%3Aaps%2Ck%3APL9823+8mm)
I provide a link to Amazon search for the WS2812 and PL9823 devices but there are many places these can be sourced from and if you can wait you can get them directly from China really cheap.

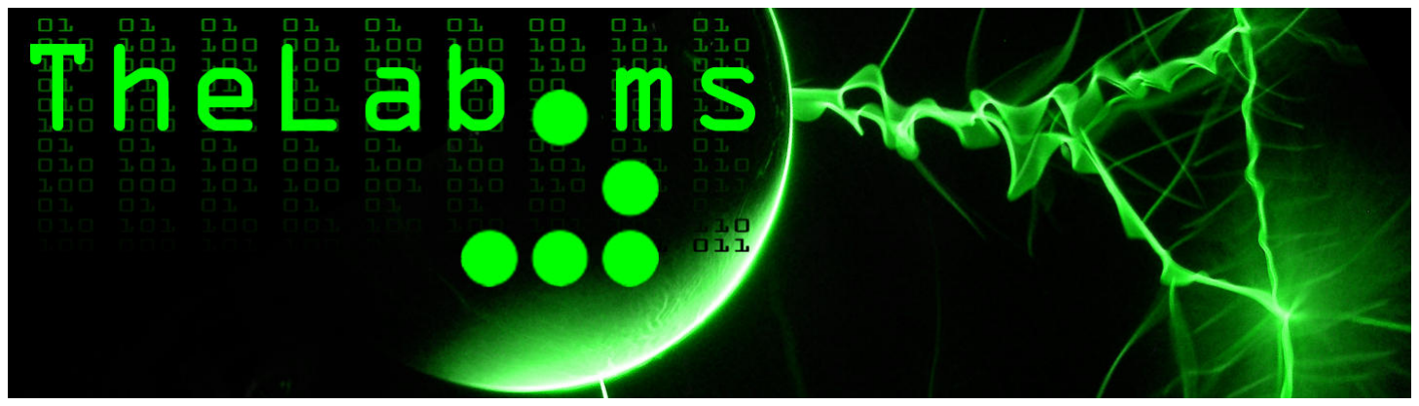
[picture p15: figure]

TheLab.ms is an all-volunteer, 501(c)(3) non-profit organization and community resource. For more information, please visit our website and consider becoming a supporting member.

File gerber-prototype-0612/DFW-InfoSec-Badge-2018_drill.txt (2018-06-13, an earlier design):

; NON-PLATED HOLES START AT T1
; THROUGH (PLATED) HOLES START AT T100
M48
INCH
T100C0.038000
T101C0.035000
T102C0.025000
T103C0.036000
%
T100
X019026Y015685
X009226Y014685
X019026Y012685
X019026Y005685
X019026Y006685
X009226Y015685
X019626Y017685
X019026Y014685
X020626Y017685
X019026Y004685
X019026Y013685
X009226Y016685
X019026Y003685
X009226Y017685
X019026Y011685
T101
X009226Y006685
X007226Y006685
X007226Y009685
X009226Y005685
X009226Y004685
X007226Y005685
X007226Y013685
X007226Y011685
X007226Y010685
X019026Y010685
X009226Y009685
X007226Y007685
X009226Y013685
X009226Y007685
X019026Y007685
X009226Y003685
X009226Y011685
X009226Y012685
X021026Y008685
X019026Y008685
X021026Y010685
X007226Y004685
X007226Y008685
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

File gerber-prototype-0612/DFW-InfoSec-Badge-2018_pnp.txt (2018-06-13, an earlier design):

*Pick And Place List
*Company=
*Author=
*eMail=
*
*Project=DFW-InfoSec-Badge-2018
*Date=19:07:50
*CreatedBy=Fritzing 0.9.3b.04.19.5c895d327c44a3114e5fcc9d8260daf0cbb52806
*
*
*Coordinates in mm, always center of component
*Origin 0/0=Lower left corner of PCB
*Rotation in degree (0-360, math. pos.)
*
*No;Value;Package;X;Y;Rotation;Side;Name
1;;5 mm [THT];22.9278;-82.4184;-90;Bottom;LED3
2;150;THT;50.8677;-24.6001;0;Bottom;R5
3;150;THT;20.8957;-29.6801;180;Bottom;R1
4;;5 mm [THT];42.7398;-67.6864;-90;Bottom;LED2
5;150;THT;20.8957;-11.9001;180;Bottom;R15
6;;THT;48.3277;-13.1701;0;Bottom;J3
7;150;THT;50.8677;-27.1401;0;Bottom;R4
8;;5 mm [THT];35.6278;-92.0704;-90;Bottom;LED4
9;9V;;51.1217;-44.9201;90;Bottom;VCC1
10;150;THT;20.8957;-22.0601;180;Bottom;R9
11;150;THT;20.8957;-9.36007;180;Bottom;R14
12;;5 mm [THT];47.3118;-82.4184;-90;Bottom;LED5
13;;THT;48.3277;-34.7601;0;Bottom;J4
14;150;THT;20.8957;-14.4401;180;Bottom;R12
15;150;THT;20.8957;-24.6001;180;Bottom;R8
16;150;THT;20.8957;-32.2201;180;Bottom;R2
17;150;THT;50.8677;-22.0601;0;Bottom;R6
18;;THT;23.4357;-41.1101;0;Bottom;J2
19;150;THT;20.8957;-27.1401;180;Bottom;R7
20;;5 mm [THT];28.0078;-67.6864;-90;Bottom;LED1
21;150;THT;20.8957;-19.5201;180;Bottom;R10
22;;;35.6277;-27.1316;0;Bottom;Part1
23;150;THT;20.8957;-34.7601;180;Bottom;R3
24;150;THT;20.8957;-16.9801;180;Bottom;R11
25;150;THT;50.8677;-19.5201;0;Bottom;R13

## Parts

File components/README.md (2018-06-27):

# Components

This section contains a list of all the components that we will be including with
the badge and information about them.

We will be including two types of LEDs and resistors and battery connectors to allow the user to choose what they like best.

## Arduino Nano v3.0

The board was designed to take an Arduino Nano v3.0 and it's associated pin out.

The place I am sourcing these from in China uses the cheaper CH340 USB chip.
This means that on some machines (Windows) you will need a CH340 driver to connect to the Arduino.

This is the link to the CH340 chip manufacturer website for details on the CH340 and driver download links:
[http://www.wch.cn/products/CH340.html](http://www.wch.cn/products/CH340.html)

## Red, Green, Blue LEDs

The board was designed to take 5mm 4-pin through hole type RGB LEDs.

I've included two types in the badge kit.  Both are very similar.

The major difference between the two is one is clear and the other is diffused. 

## Resistors

The board was designed to take through hole type resistors.

I've included two types in the badge kit.

The 220 ohm resistors that have been included are the lowest resistance I would recommend using with these LEDs.
Using these will make for very bright LEDs but will do so at the cost of battery life.
If you are planning on using a 9V battery then this should be fine.

The 470 ohm resistors that have been included are the resistance I would recommend for these LEDs when powered by coin cells.
The LEDs are still faily bright but reducing the current drawn a bit more than with the 220's extends the battery life of the coin cells.

## Battery related items

The board was designed to take input voltage between 6 and 12 volts on two leads.

I've included two types of battery connectors in the badge kit, a 9v and a 6v (2x3v CR2032).
Since the 6v coin cell holder is smaller and lighter than a big 9v battery I assumed this would be the preffered choice and have
included CR2032 batteries in the kit.
Finally I included 1x2 pin male and female headers to allow for the battery connectors to be removable should you choose to use them.

The 9v battery connector is the simple standard type used on many arduino projects.  So even if you don't use it on this badge,
it could come in handy on other projects.

The 6v coin cell holder is a fairly new thing I found that works with the Arduino.  

I was worried that the voltage drop across the VIN port on the Arduino would be too great for a 6V power source to work, but it does.  
This does mean that the coin cells do not last as long as they might otherwise since they might still have stored power that is just 
not providing enough voltage to power the board.
However, my testing seems to indicate that they last long enough for this to be a viable battery solution for the badge.
Note: If the batteries seems to be powering the Arduino (red light) but stop lighting the RGB LEDs, I have found that turning them
off for a few minutes will allow them to operate properly again for a while when turned back on since the voltage loss recovers a bit with rest.

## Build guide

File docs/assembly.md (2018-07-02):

# DFW Hacker Badge Assembly Instructions

This page will walk through the detailed assembly instructions for the DFW Hacker Badge complete with pictures for each step.

If you are new to soldering you should review this training material I put together:
[Electronics Soldering Basics](http://solder.altbier.us/)

If you are new to Electronics or the Arduino you should review this training material I put together:
[Arduino for Beginners](http://arduino.altbier.us/)

Without further preamble here are the instructions:

# The Badge Kit

This is the badge kit you should have.

Badge Kit Image

The are a few choices you need to make before you begin soldering components.

* Which LEDs will you use?  Clear or Diffused?
* Which resistors will you use?  220 ohm or 470 ohm?
* Which battery connector will you use?  6V dual coin cell or 9V?

Once these choices are made it is just a matter of putting the components onto the PCB.

# Prepare you workspace

Make sure you have a safe space to work with the appropriate tools at hand.

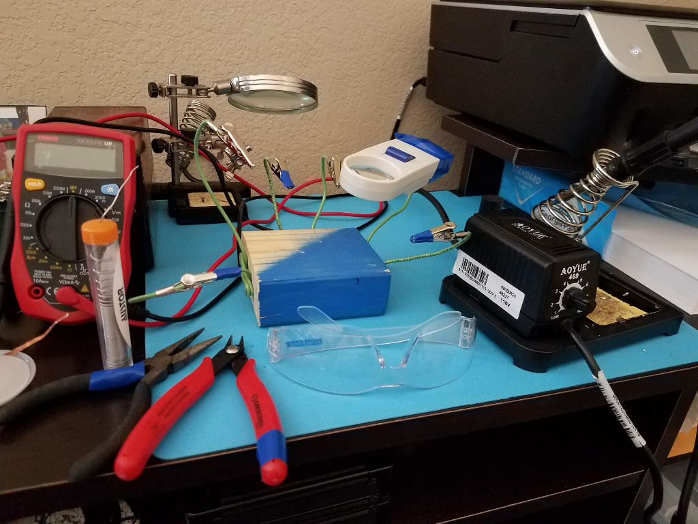
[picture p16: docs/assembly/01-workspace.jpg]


# Add the Arduino to the PCB

The Arduino Nano which came in your kit has been designed to be placed in the lower center of
the PCB where the white rectangle is drawn on the front of the PCB.

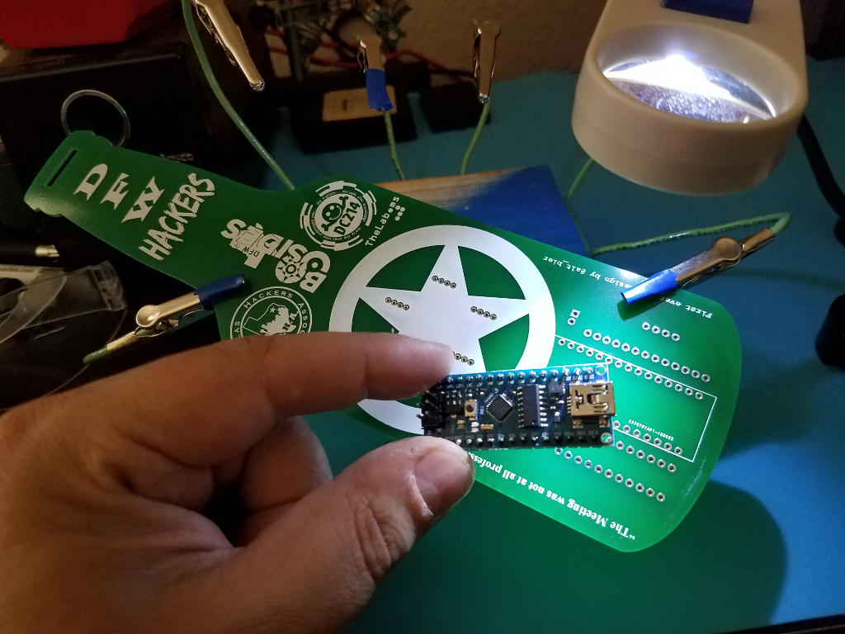
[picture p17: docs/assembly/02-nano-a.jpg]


Plug the Arduino into the front of the PCB by pushing its header pins into the appropriate holes.

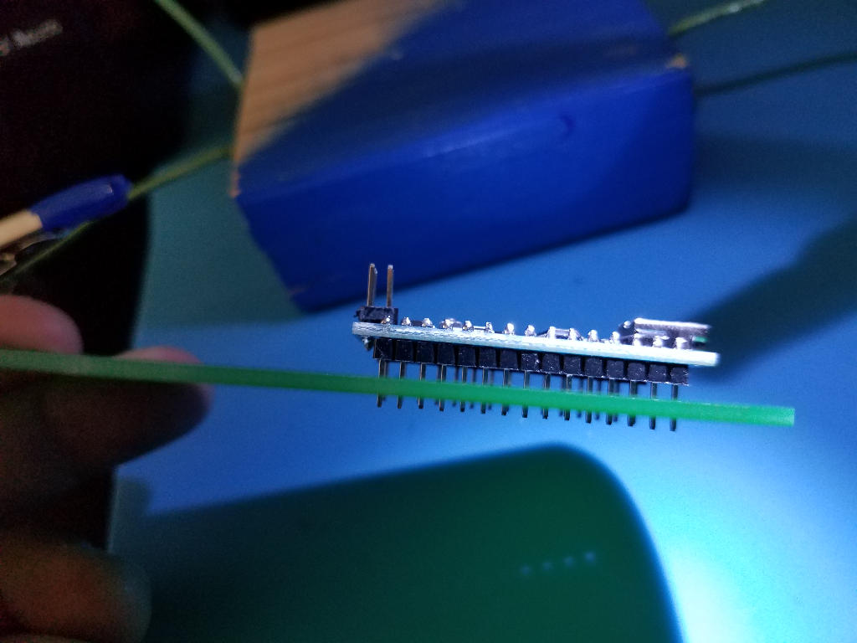
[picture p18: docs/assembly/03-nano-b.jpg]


It should be a tight fit but make sure the Arduino is pushed all the way down to where the
plastic on the Arduino headers are flush with the PCB surface.

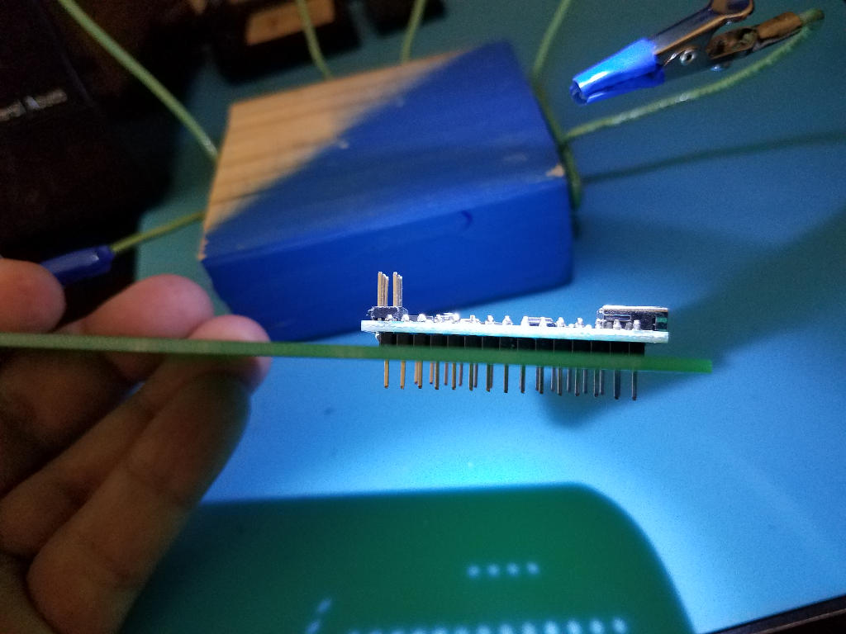
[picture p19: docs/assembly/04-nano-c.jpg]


Flip the PCB over so that the header pins poking through are clearly visible.
You will be soldering on this side of the PCB.

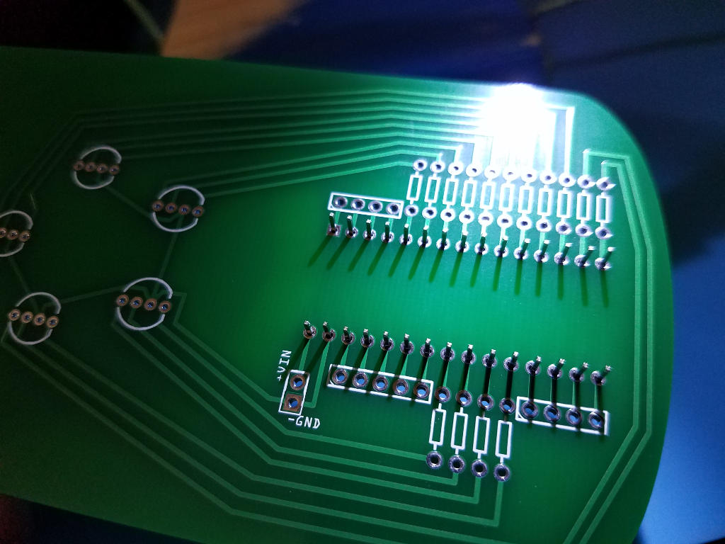
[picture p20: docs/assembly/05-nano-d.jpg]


Secure the PCB and Solder each pin to the pad surrounding the hole on the PCB.
Press the iron to both the PCB pad and a pin the add solder to join them.
Repeat this process for each of the Nano pins.

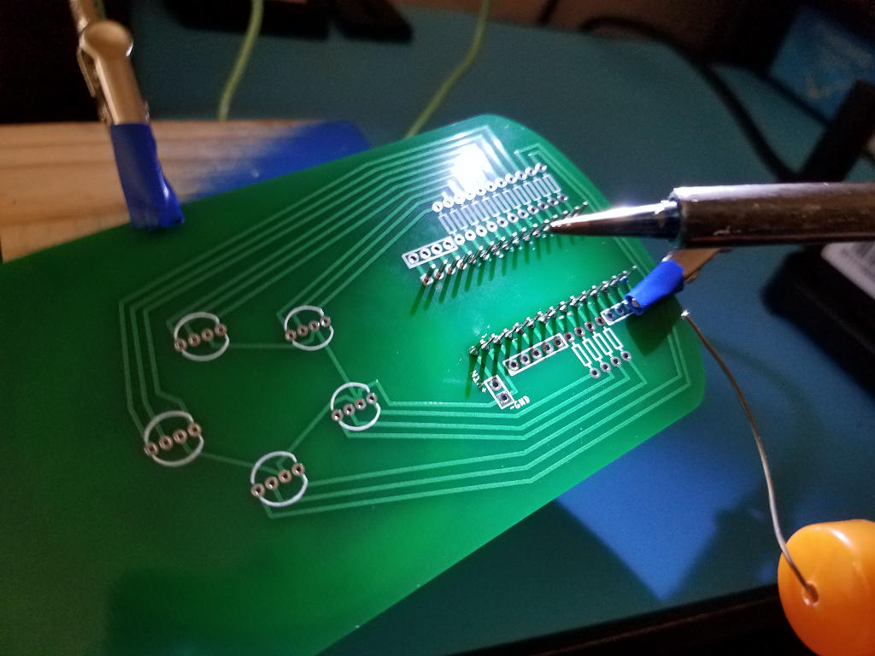
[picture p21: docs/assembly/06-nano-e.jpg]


Inspect each solder joint and correct as needed.
The solder joints should look like little volcanos.  Any other shape is an indication
of a problem that needs to be corrected.

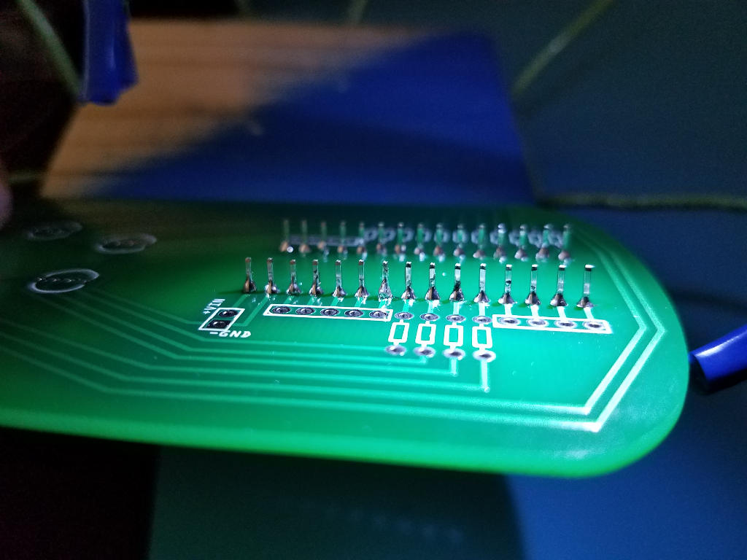
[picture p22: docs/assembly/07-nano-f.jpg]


# Add the resistors to the PCB

Unlike the header pins on the Arduino, the resistors have soft leads that are easy to bend
Bend each resistor into a U shape (with the resistor at the bottom of the U)

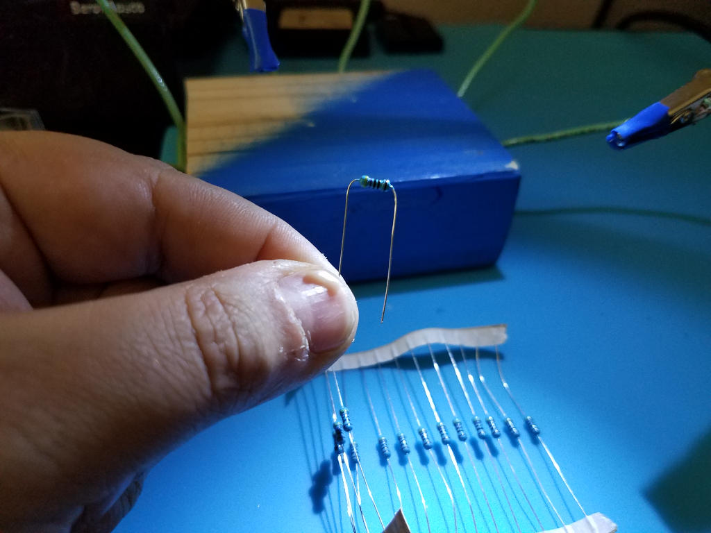
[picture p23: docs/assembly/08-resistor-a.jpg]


Push each resistors leads into appropriate holes in the front of the PCB

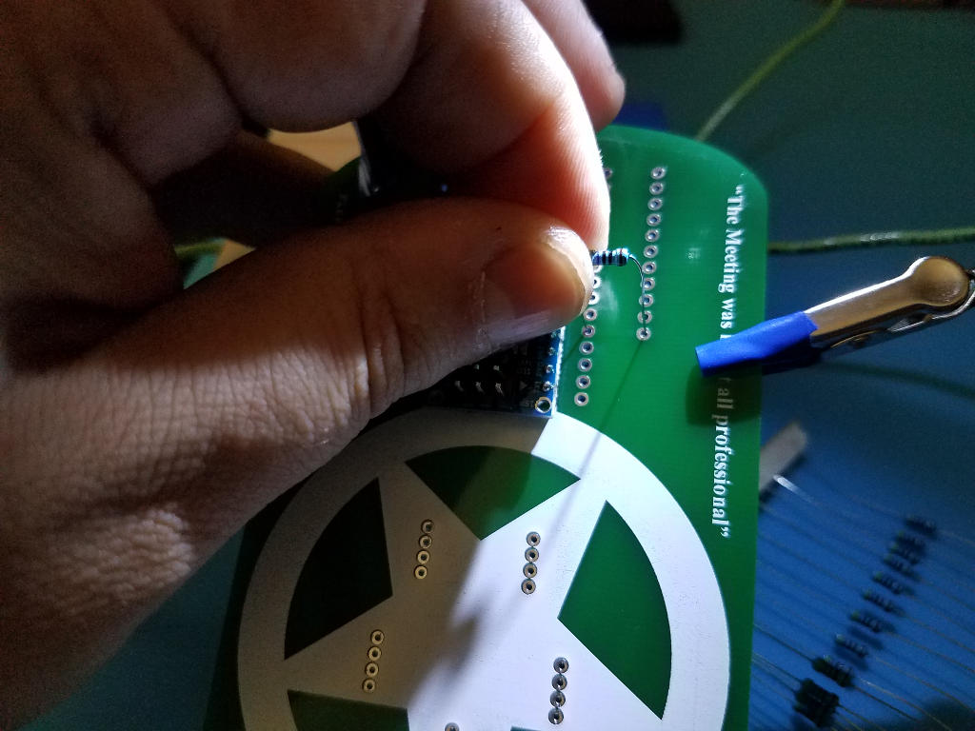
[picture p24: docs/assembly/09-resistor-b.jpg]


Do this for as many resistors as you wish to solder at a time.

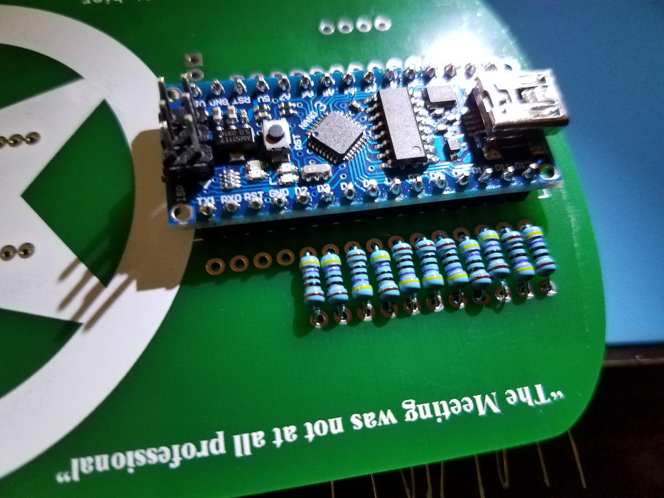
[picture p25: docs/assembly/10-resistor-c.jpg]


This will be a very loose fit so take care to hold the resistors in place as you flip the PCB over
On the back of the PCB bend the leads outward at 45 to 90 degrees to hold the resistor in place

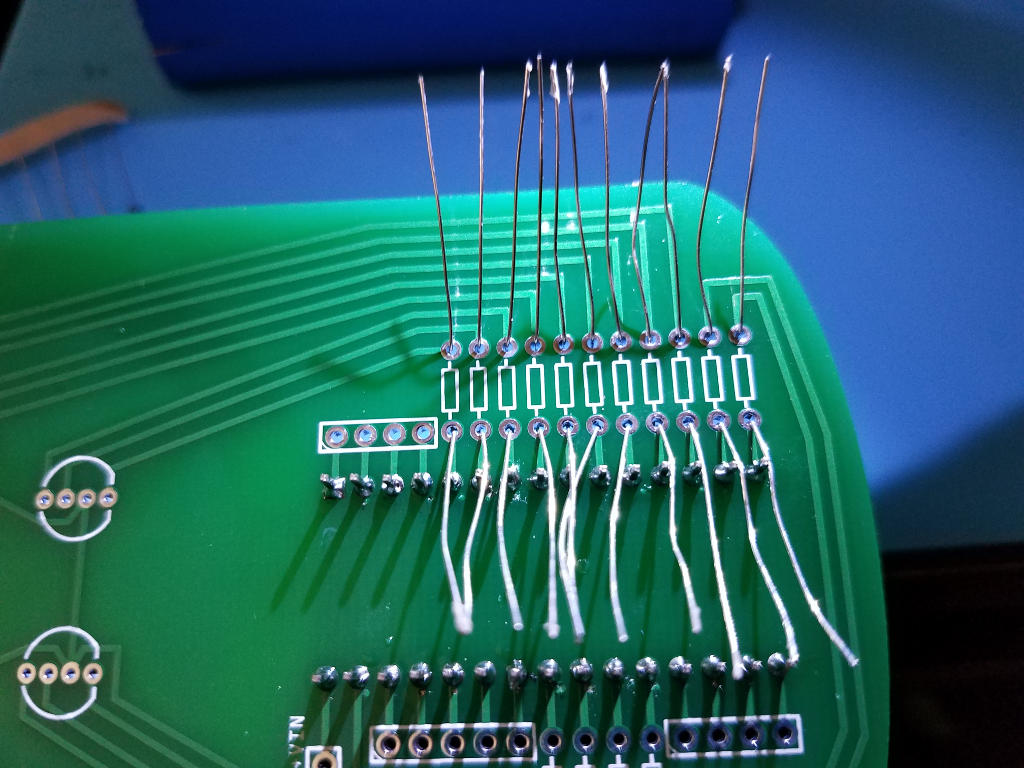
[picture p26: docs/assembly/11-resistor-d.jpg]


Solder each lead of the resistor to the pad surrounding the hole on the PCB.
Inspect each solder joint and correct as needed.

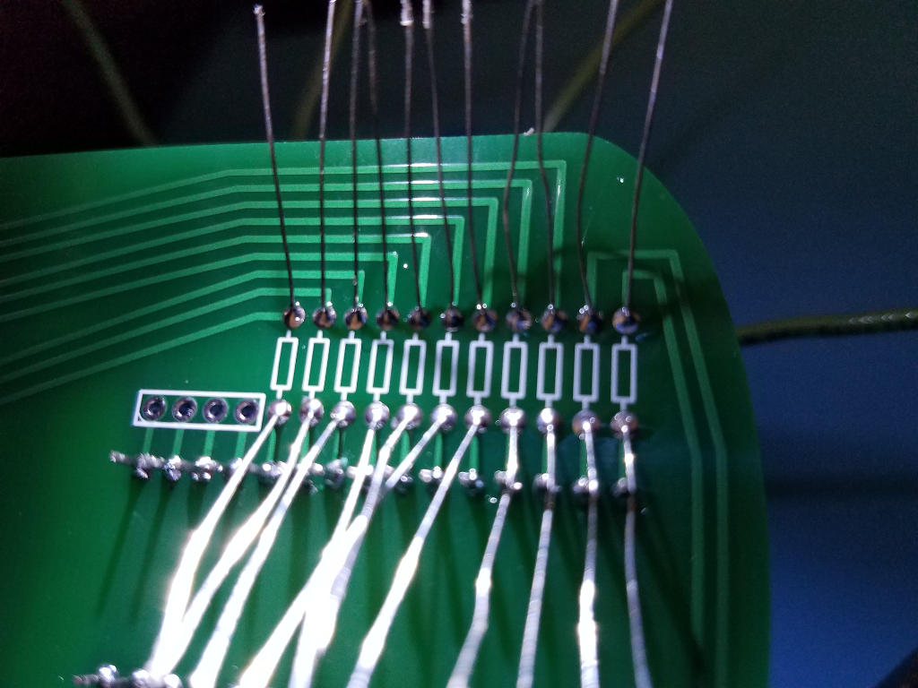
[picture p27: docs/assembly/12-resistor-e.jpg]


Repeat this process for the remaining resistors.

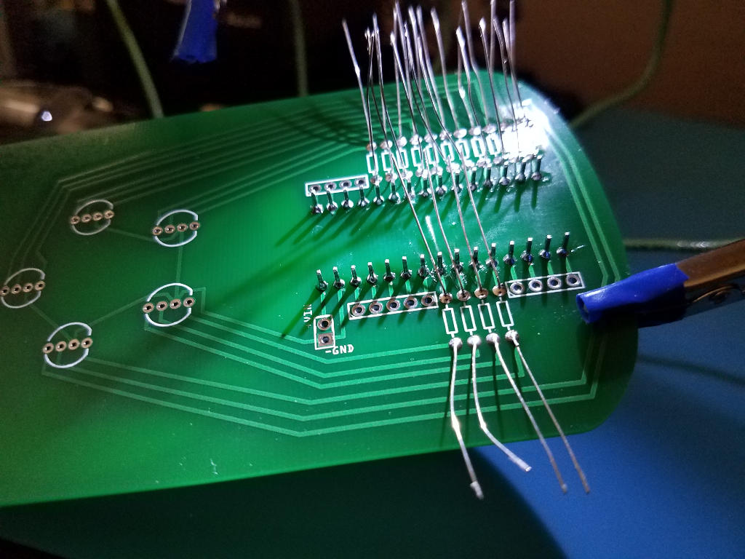
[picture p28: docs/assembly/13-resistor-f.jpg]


# Add the LEDs to the PCB

Prepare to plug an LED into the PCB by orienting the LED correctly so the common cathode
pin goes into the correct hole.
* Each LED will have one pin longer than the others, this is the common cathode pin
* You can tell the common cathode hole on the PCB by looking at the traces on the back
* The common cathode holes for all five LEDs will be connected together by traces

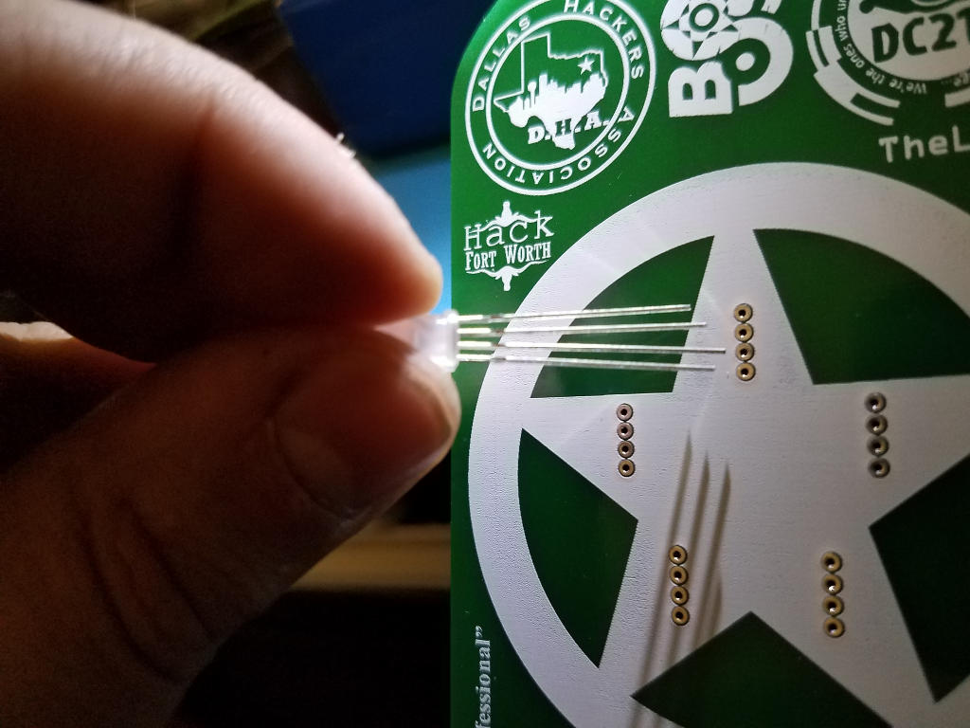
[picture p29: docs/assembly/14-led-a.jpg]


Plug each LED into the front of the PCB by pushing its header pins into the appropriate holes

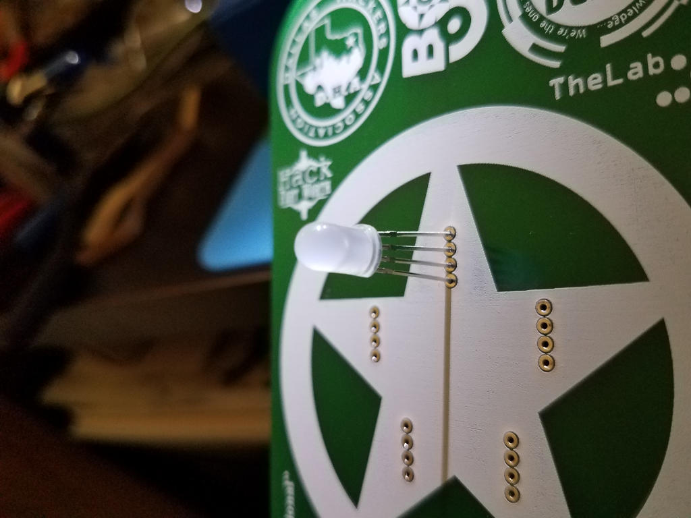
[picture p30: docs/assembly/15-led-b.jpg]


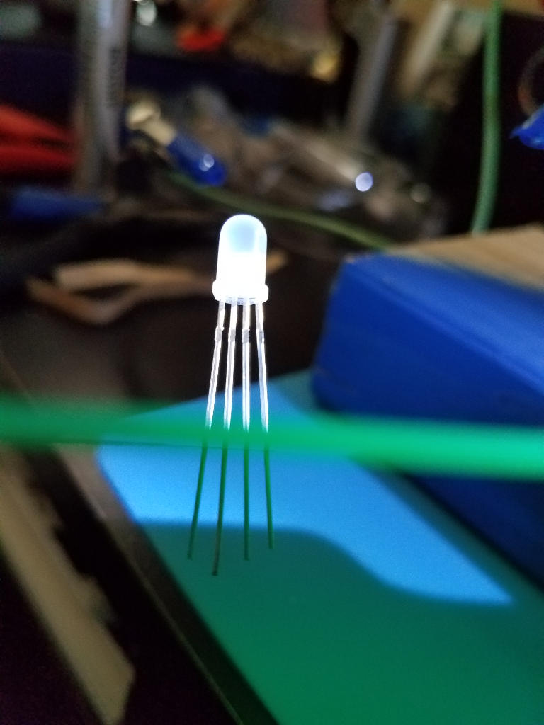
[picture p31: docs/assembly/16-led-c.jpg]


It'll be a tight fit but make sure the LED is pushed all the way down to the pin stops
These are small extrusions on the LED pins that prevent them from passing thru the holes.
Do not try to force the LED all the way down to where its plastic is touching the PCB.

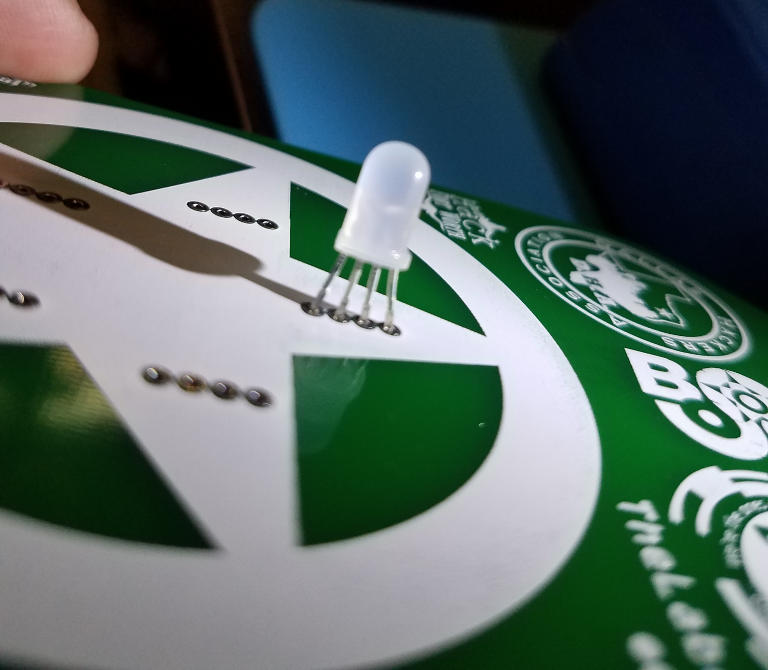
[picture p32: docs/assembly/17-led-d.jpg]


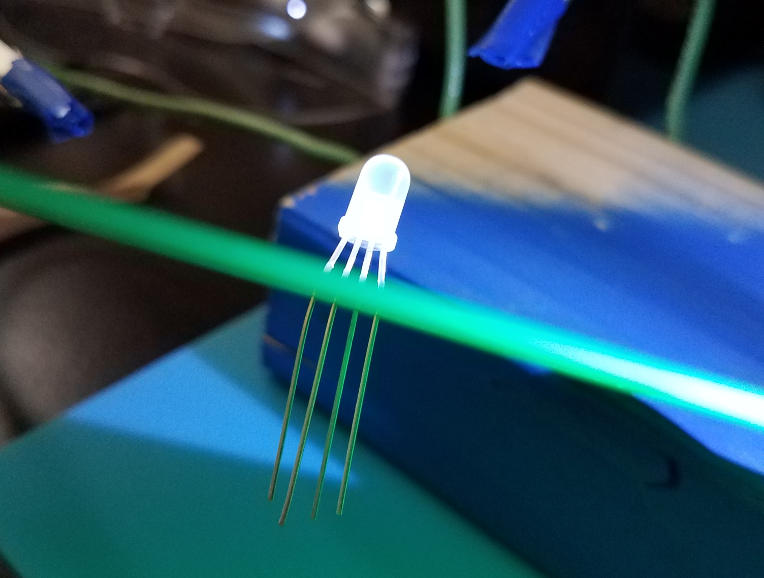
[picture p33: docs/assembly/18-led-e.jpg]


Flip the PCB over so that the LED pins poking through are clearly visible

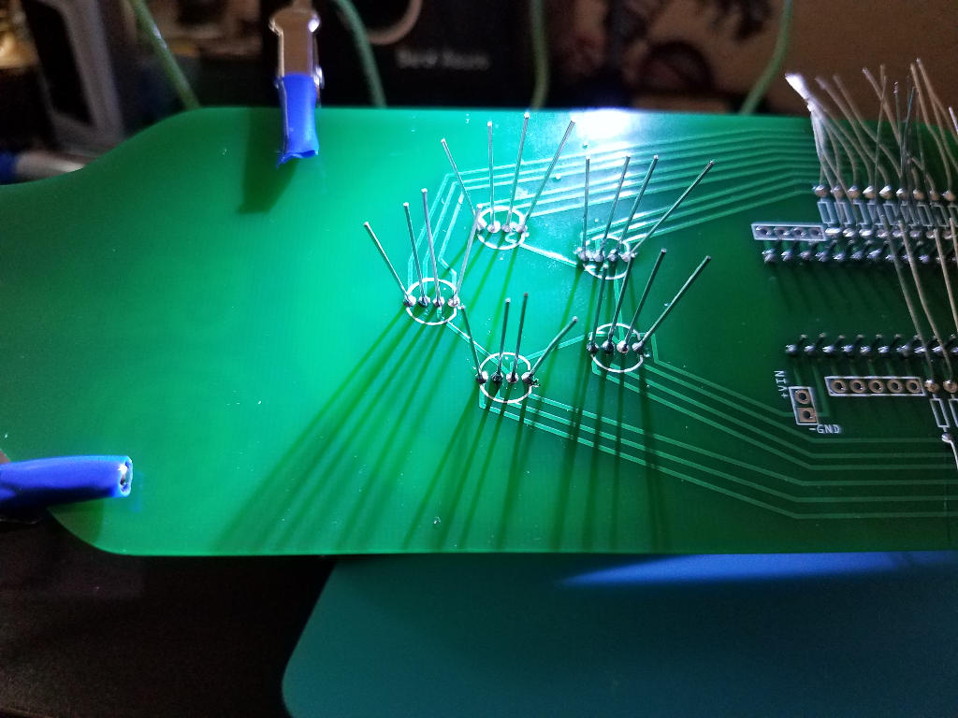
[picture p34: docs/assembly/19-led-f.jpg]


Solder each pin to the pad surrounding the hole on the PCB.
Inspect each solder joint and correct as needed

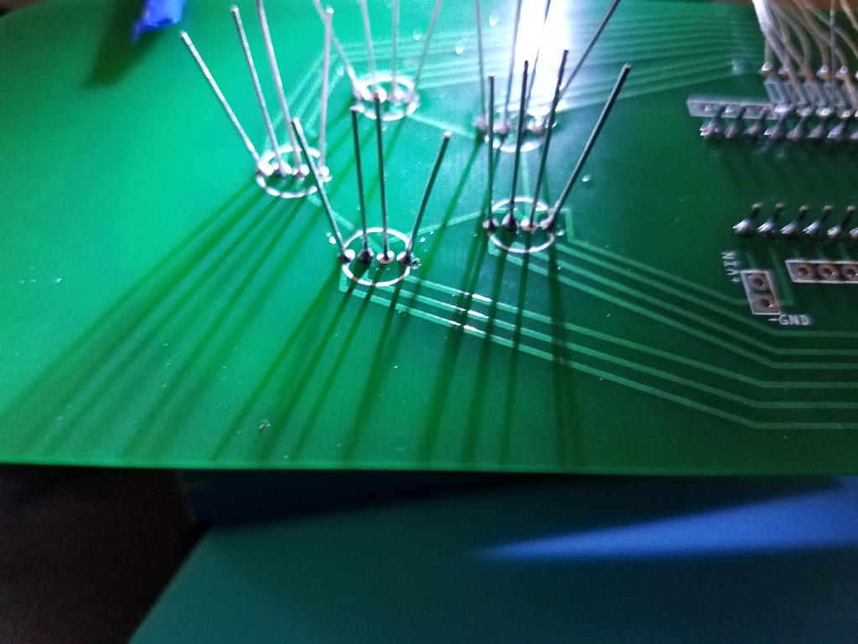
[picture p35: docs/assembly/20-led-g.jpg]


# Trim excess pins and leads

On the backside of the PCB cut the header pins and leads off just above each solder joint.
Be careful not to damage the solder joint while cutting.

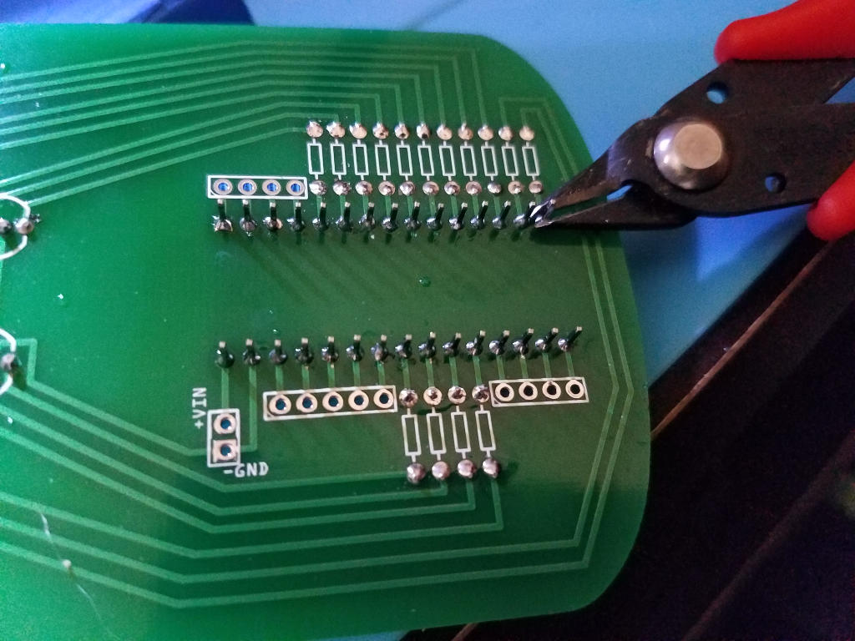
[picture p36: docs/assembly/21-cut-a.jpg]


When complete the back of the PCB should look fairly level with just small bumps for each solder joint.

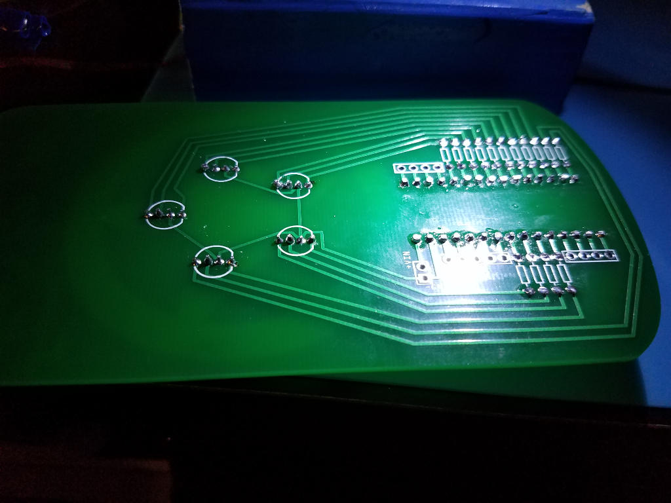
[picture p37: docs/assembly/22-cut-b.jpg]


# Add the battery connector to the PCB

This assembly guide assumes that you chose to install the 6V two coin cell battery holder instead of the 9V.

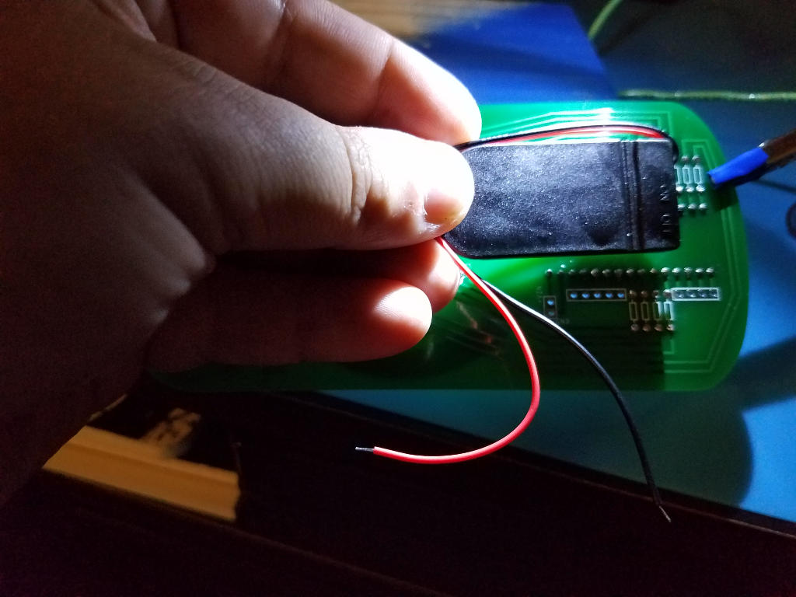
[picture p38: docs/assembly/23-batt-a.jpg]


Trim the lead wires to the size needed.

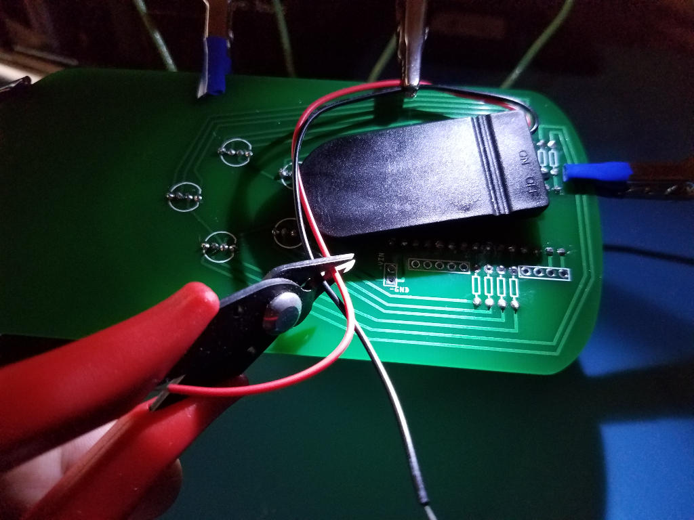
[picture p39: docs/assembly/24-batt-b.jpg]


Strip the end of each lead wire to expose about 1/4 inch of wire.

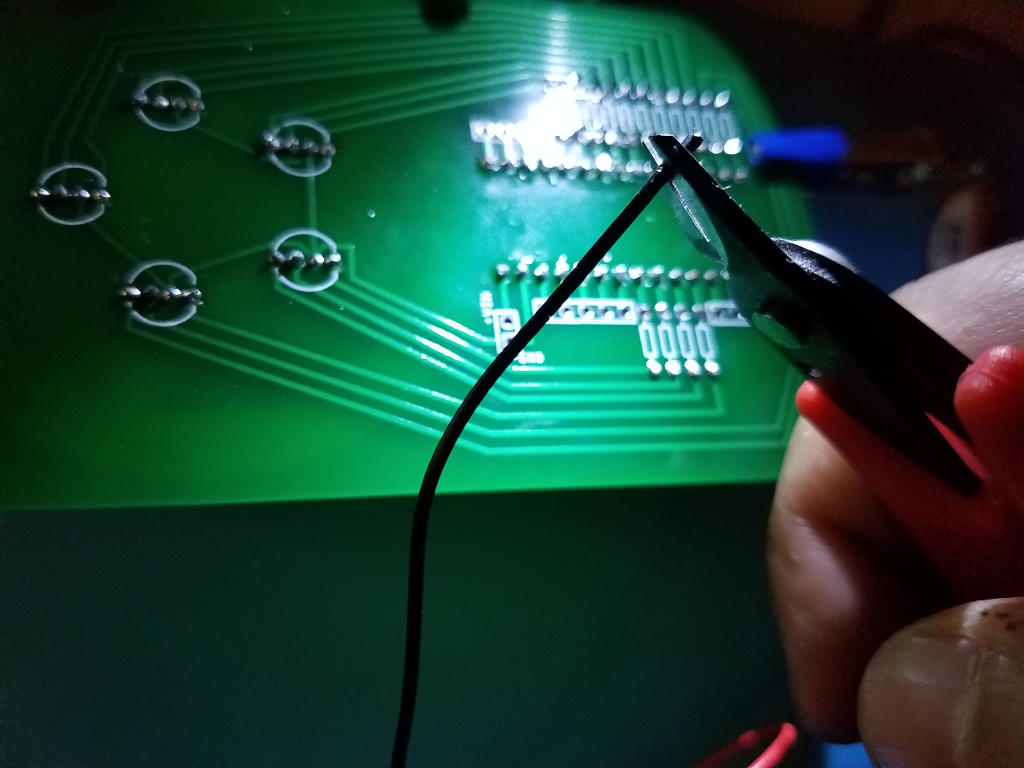
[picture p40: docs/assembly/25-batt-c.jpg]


"Tin" the lead wires by adding a bit of solder to them.

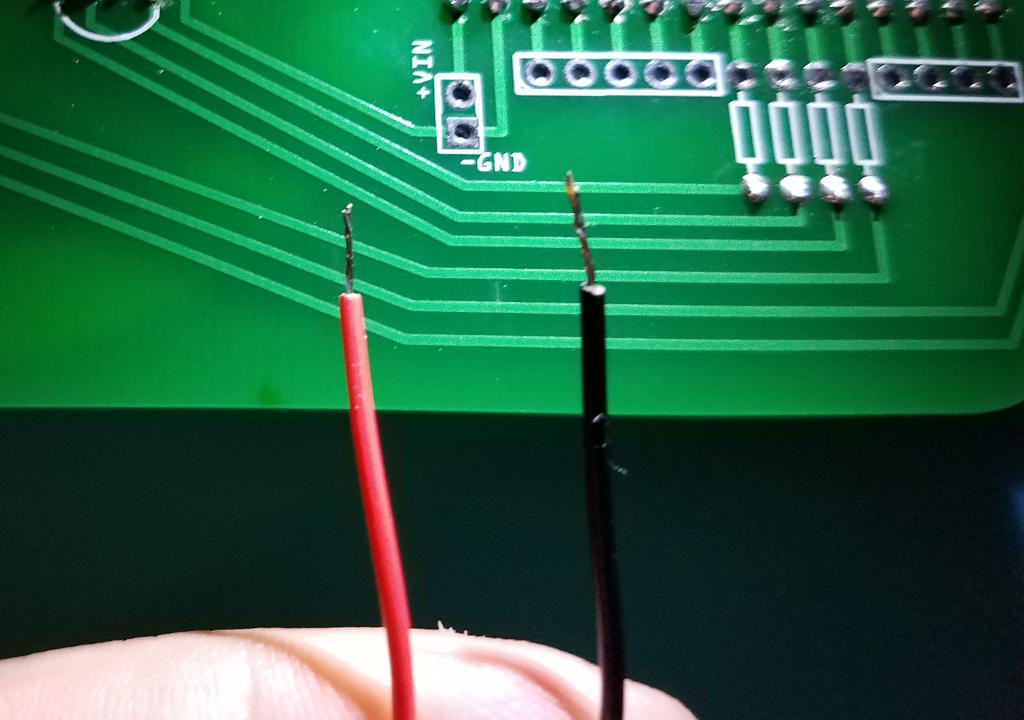
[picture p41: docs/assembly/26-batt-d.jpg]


Plug the bare end of a lead wire into the appropriate power hole in the back of the PCB
Red goes to +VIN and Black goes to -GND
Secure the wire in place so that is does not move in the PCB hole

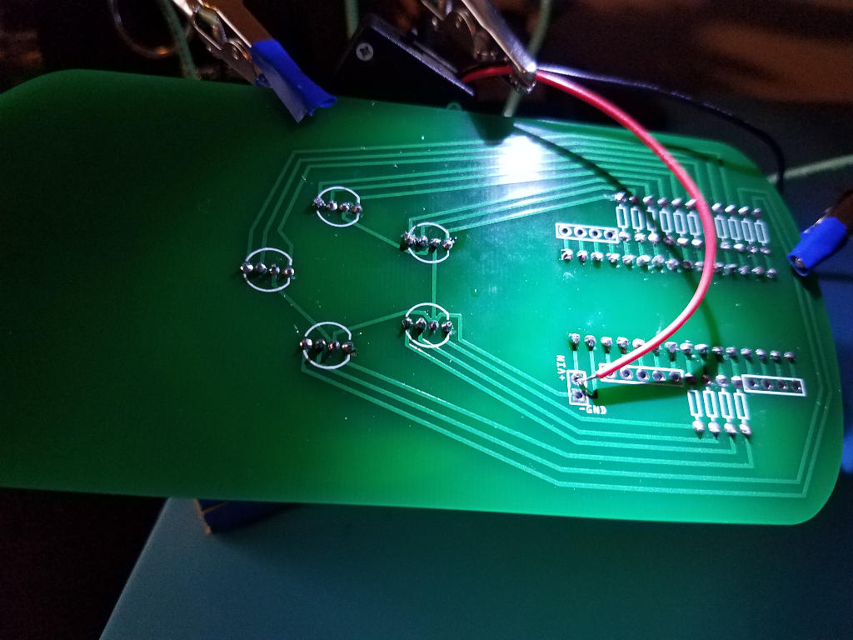
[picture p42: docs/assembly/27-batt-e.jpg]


Solder the wire to the pad surrounding the hole on the PCB.

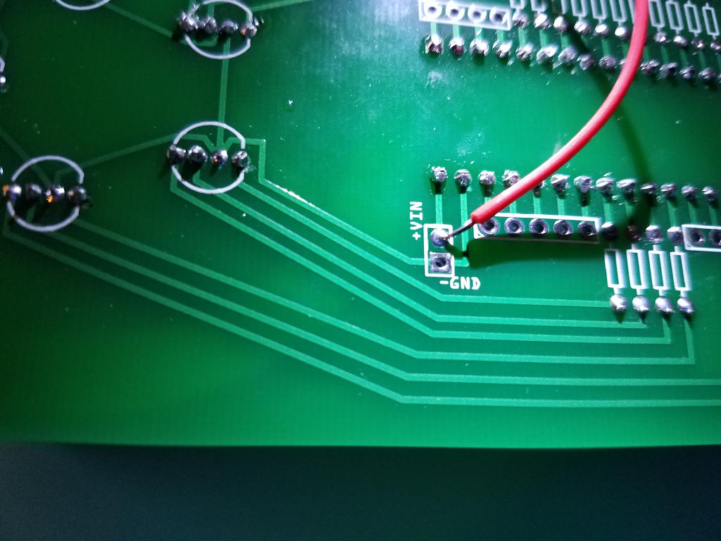
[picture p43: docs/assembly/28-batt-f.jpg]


Repeat this process for the second lead wire.

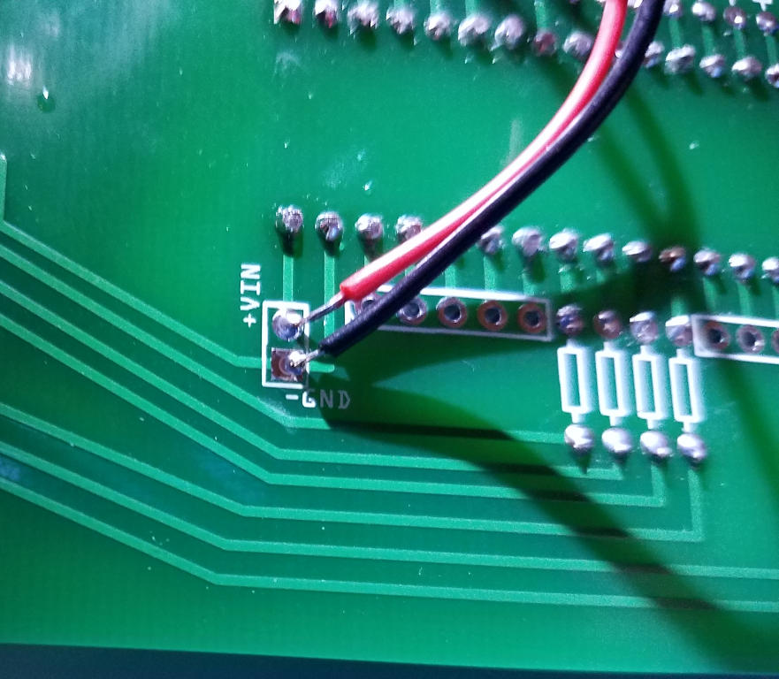
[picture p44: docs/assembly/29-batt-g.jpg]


Trim any excess wire protruding from the front side of the PCB.

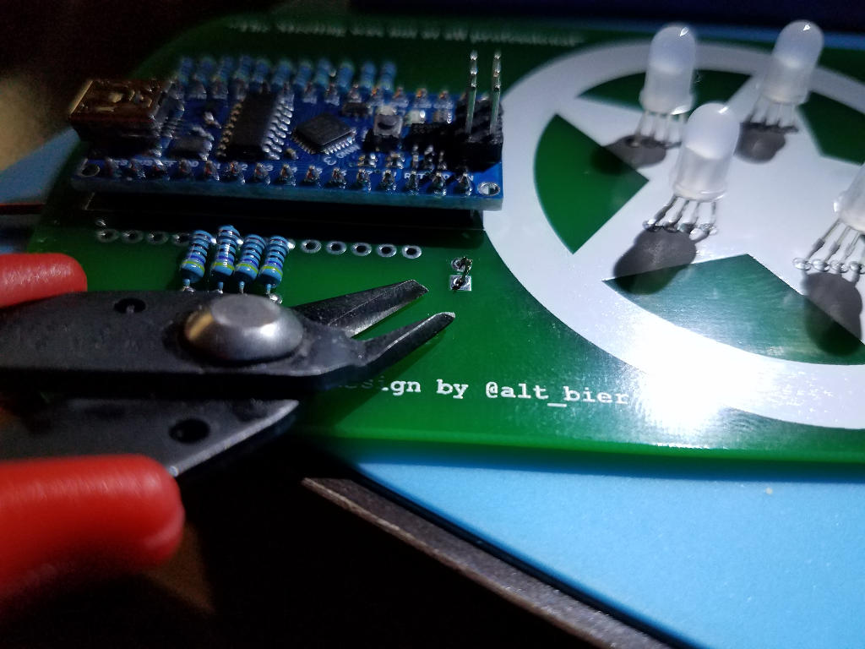
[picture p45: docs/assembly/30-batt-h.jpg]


Add a piece of Velcro to the back side of the PCB where the battery holder will be placed.

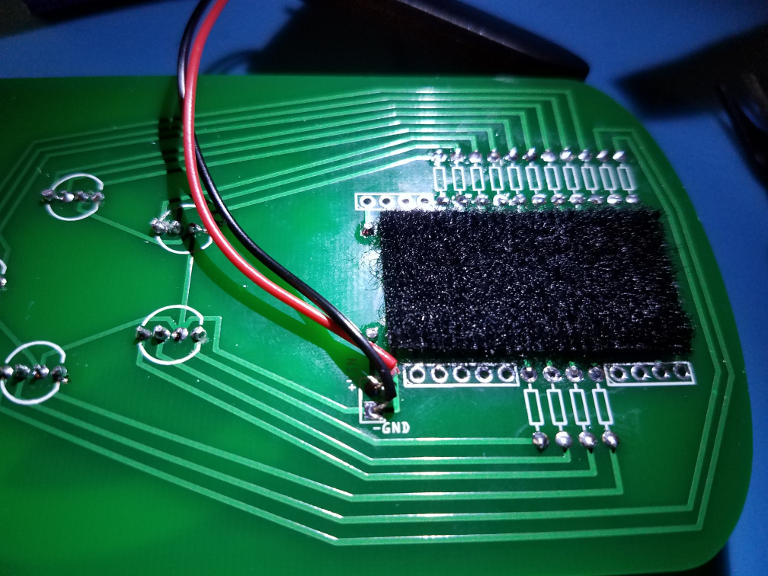
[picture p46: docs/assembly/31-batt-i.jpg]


Add a piece of Velcro to the back side of the battery holder

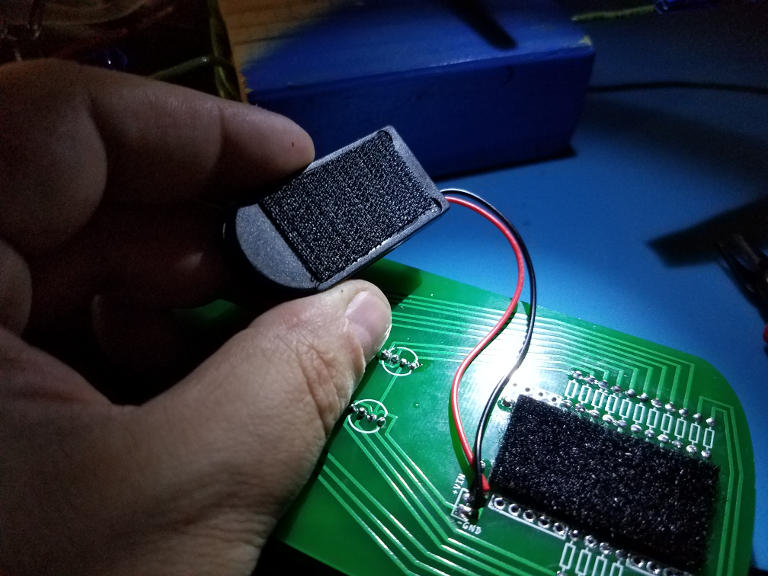
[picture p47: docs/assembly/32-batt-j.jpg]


Attach the battery holder to the back of the PCB using the Velcro

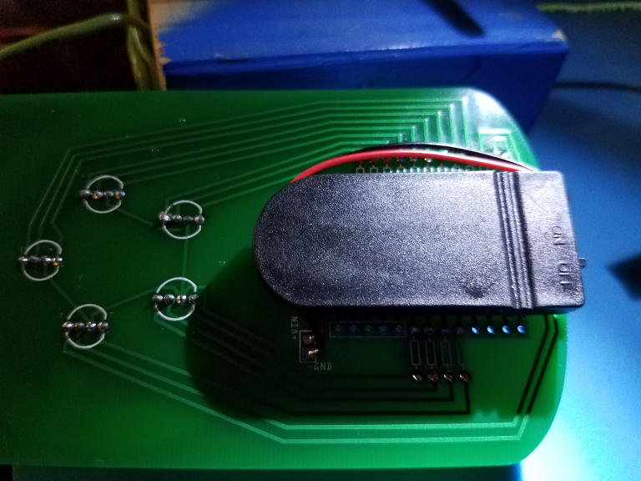
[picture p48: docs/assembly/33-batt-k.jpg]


If applied correctly the battery holder should be nearly flush with the PCB.

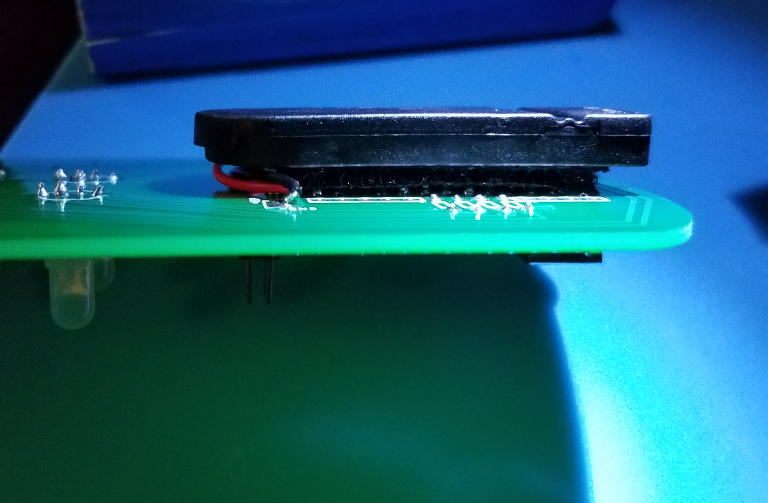
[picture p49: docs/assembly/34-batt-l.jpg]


The battery holder takes two CR2032 batteries placed into it in opposite directions.

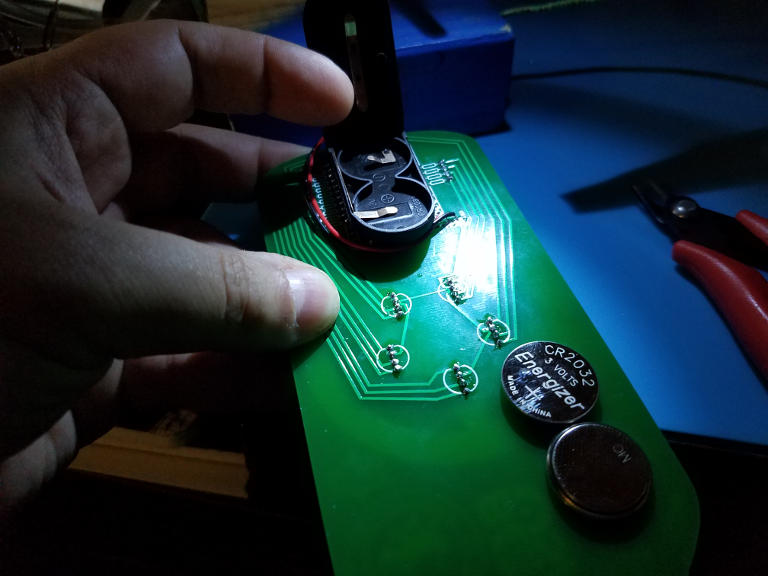
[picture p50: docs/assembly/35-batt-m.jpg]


Be sure you confirm that you a placing the batteries into the holder in the correct position!
Putting the batteries in backwards can cause damage to your Arduino.  So this is important.

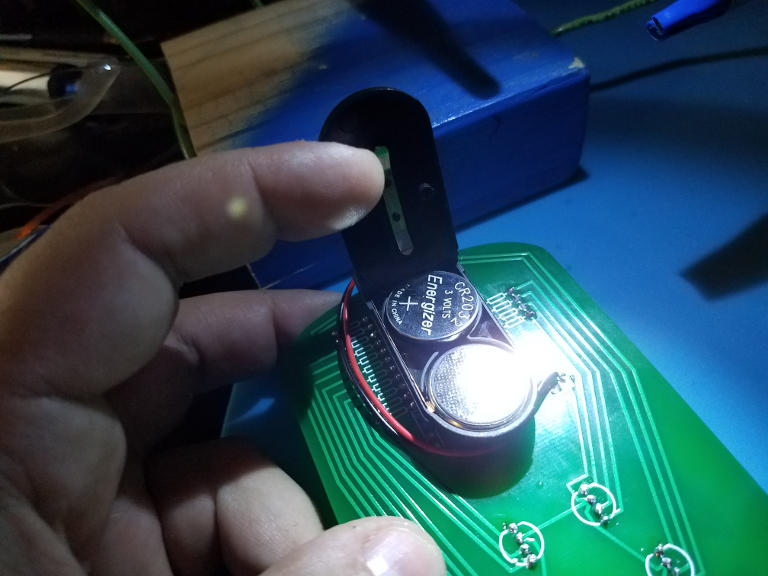
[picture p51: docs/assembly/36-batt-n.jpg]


The battery holder should snap shut and stay shut.  Verify it is secure.

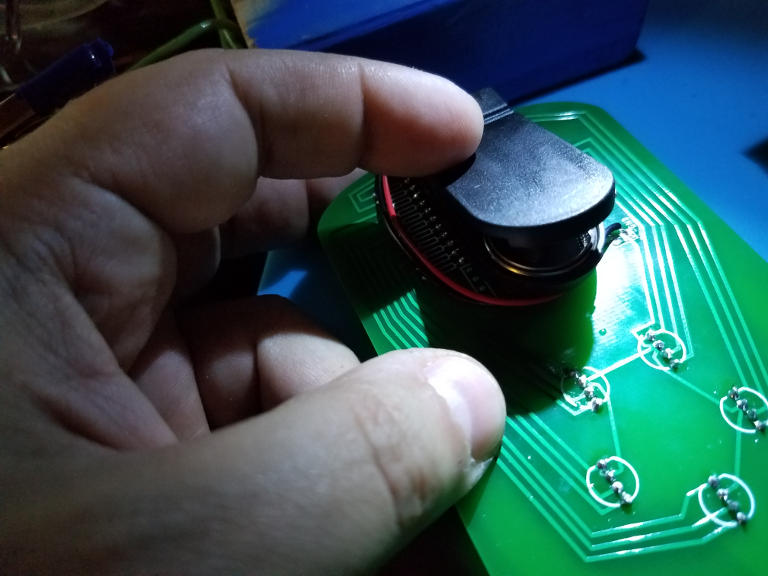
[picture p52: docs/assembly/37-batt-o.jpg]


# Turn it on and enjoy

If everything is done correctly then when you turn it on the preprogrammed Arduino should
start lighting up the LEDs in a color pattern.

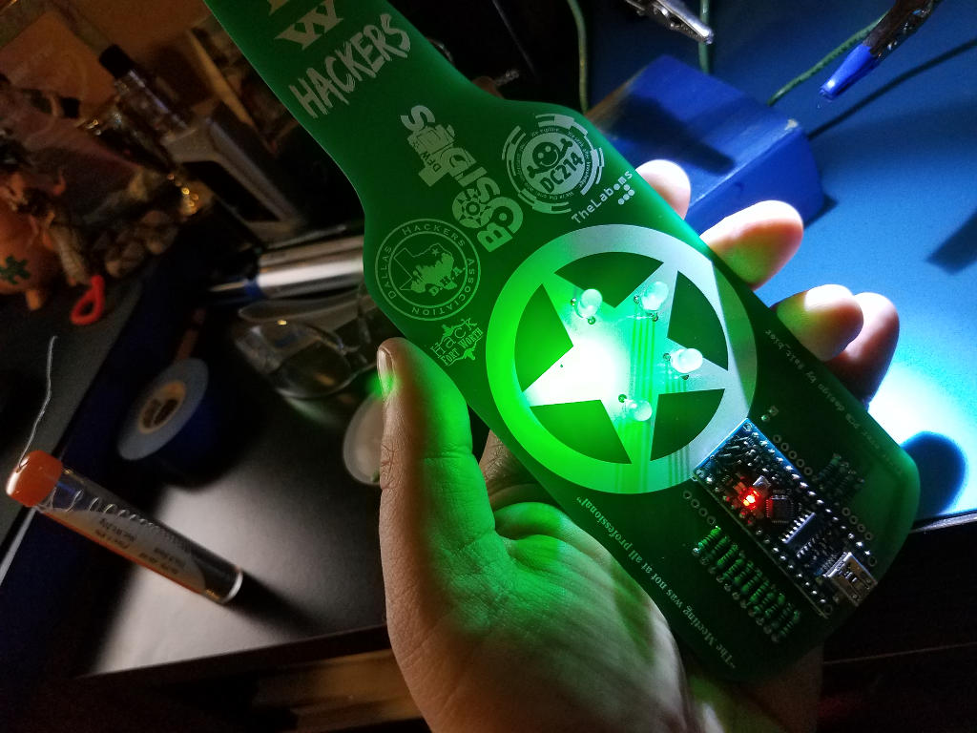
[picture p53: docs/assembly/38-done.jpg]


I hope this guide is helpful.

-- [@alt_bier](https://twitter.com/alt_bier)

[BACK HOME](/)

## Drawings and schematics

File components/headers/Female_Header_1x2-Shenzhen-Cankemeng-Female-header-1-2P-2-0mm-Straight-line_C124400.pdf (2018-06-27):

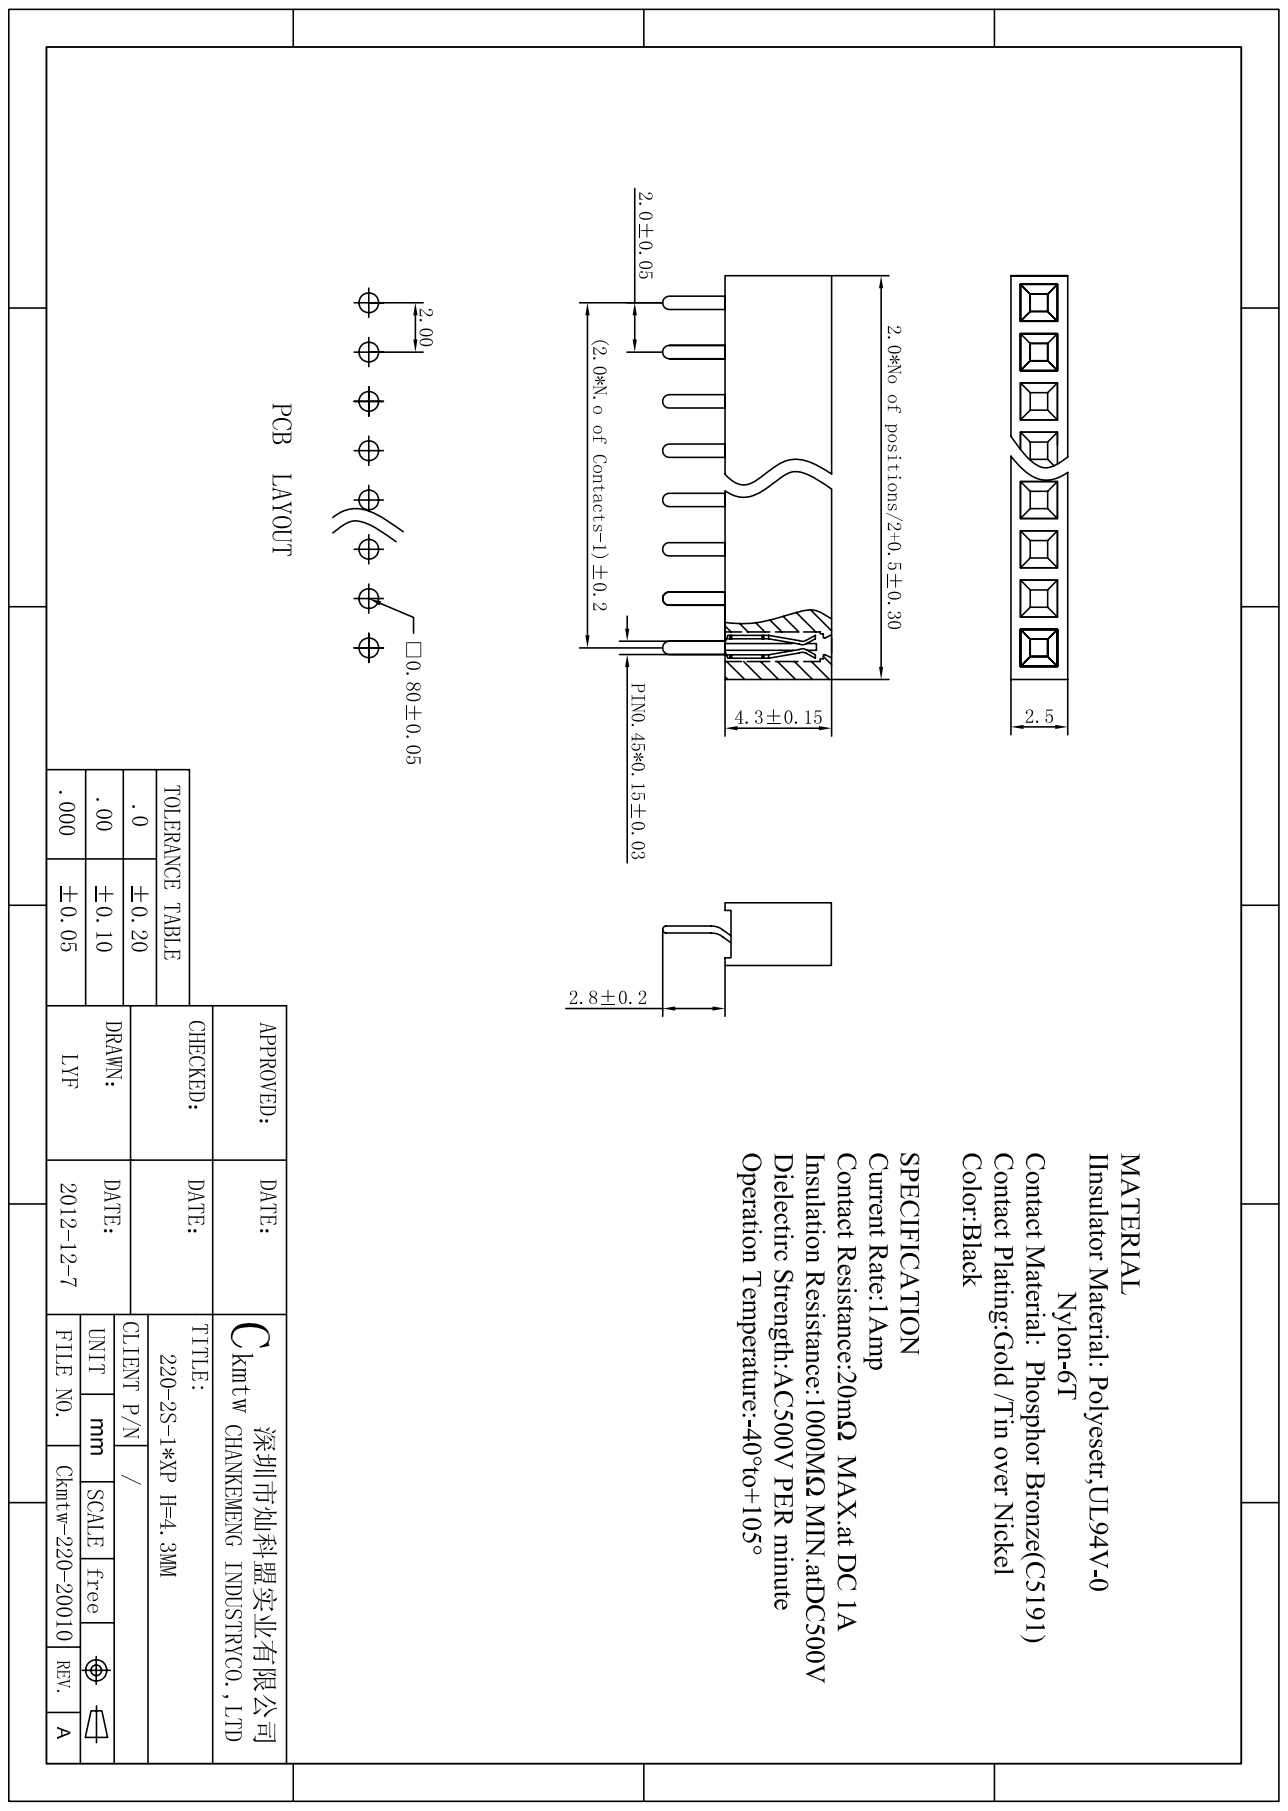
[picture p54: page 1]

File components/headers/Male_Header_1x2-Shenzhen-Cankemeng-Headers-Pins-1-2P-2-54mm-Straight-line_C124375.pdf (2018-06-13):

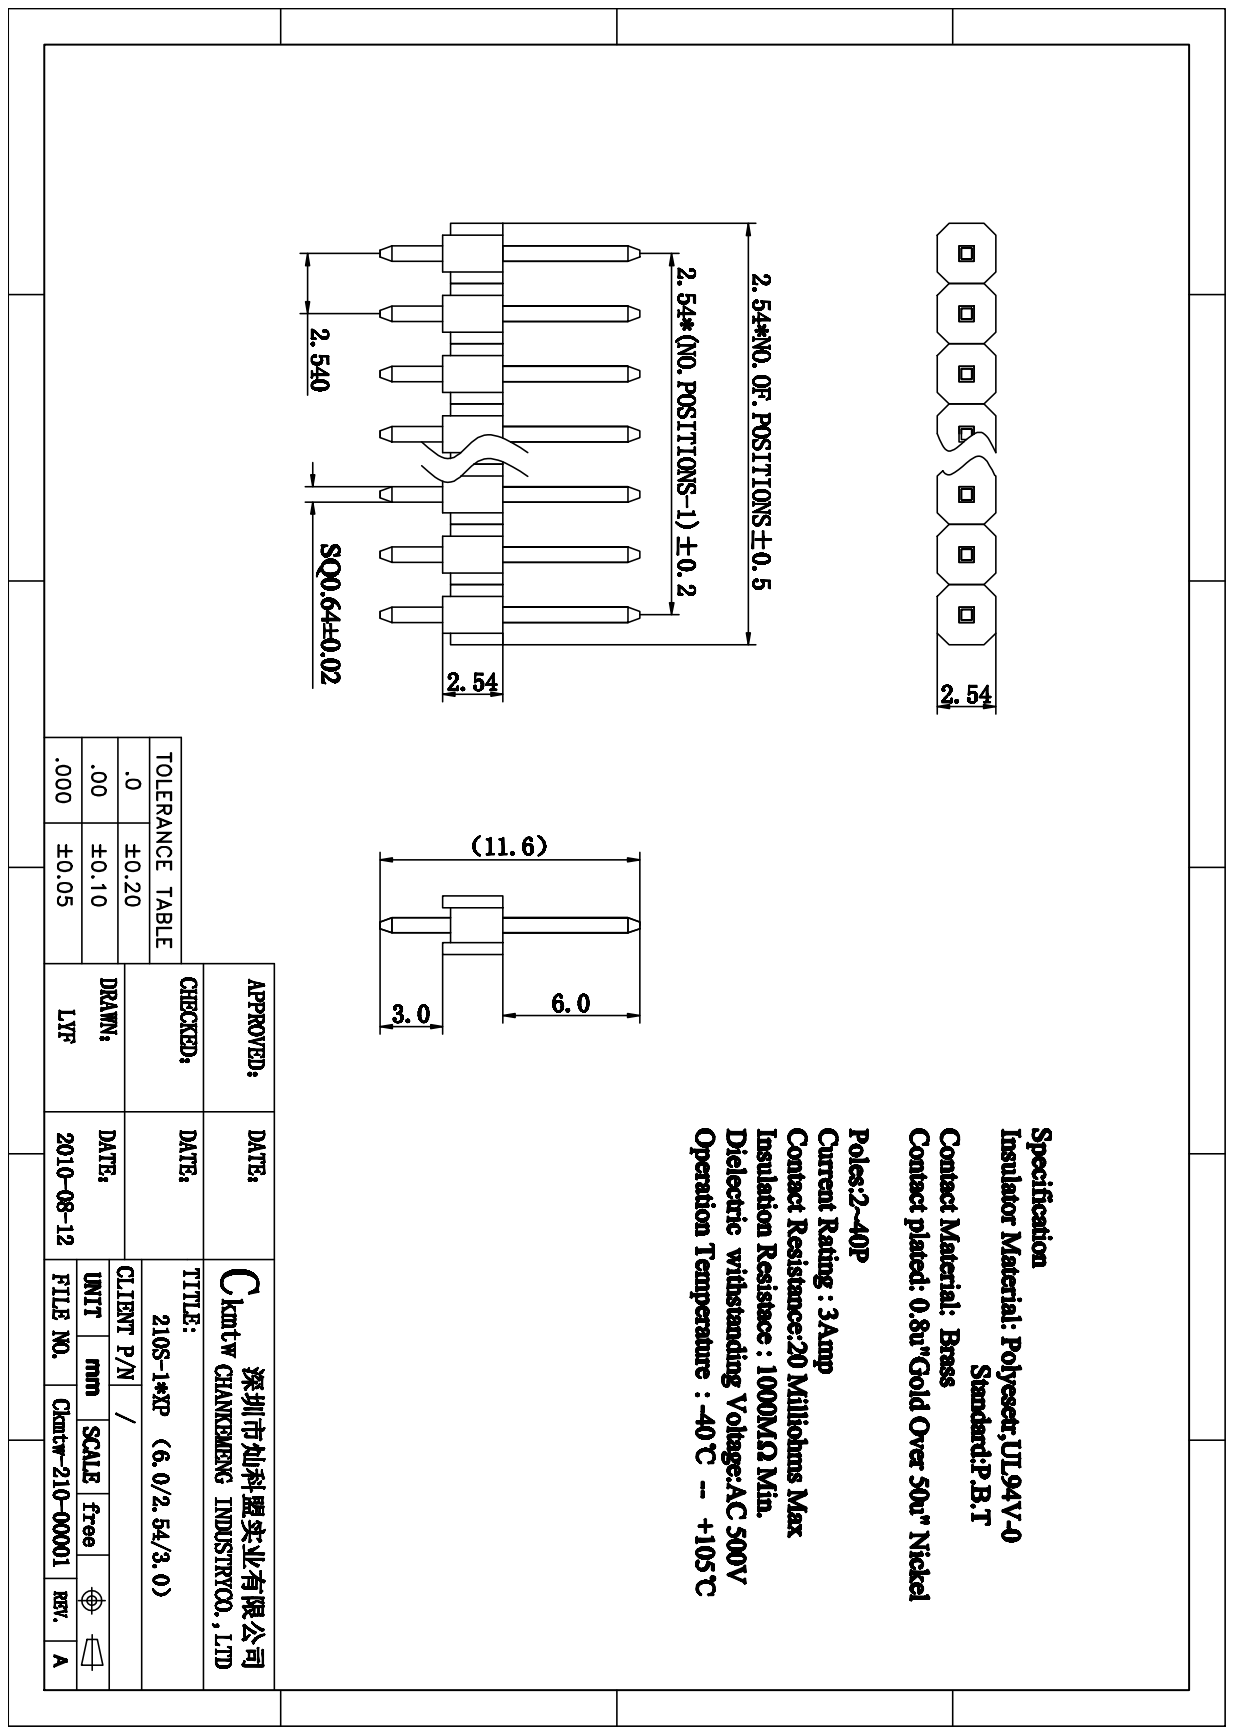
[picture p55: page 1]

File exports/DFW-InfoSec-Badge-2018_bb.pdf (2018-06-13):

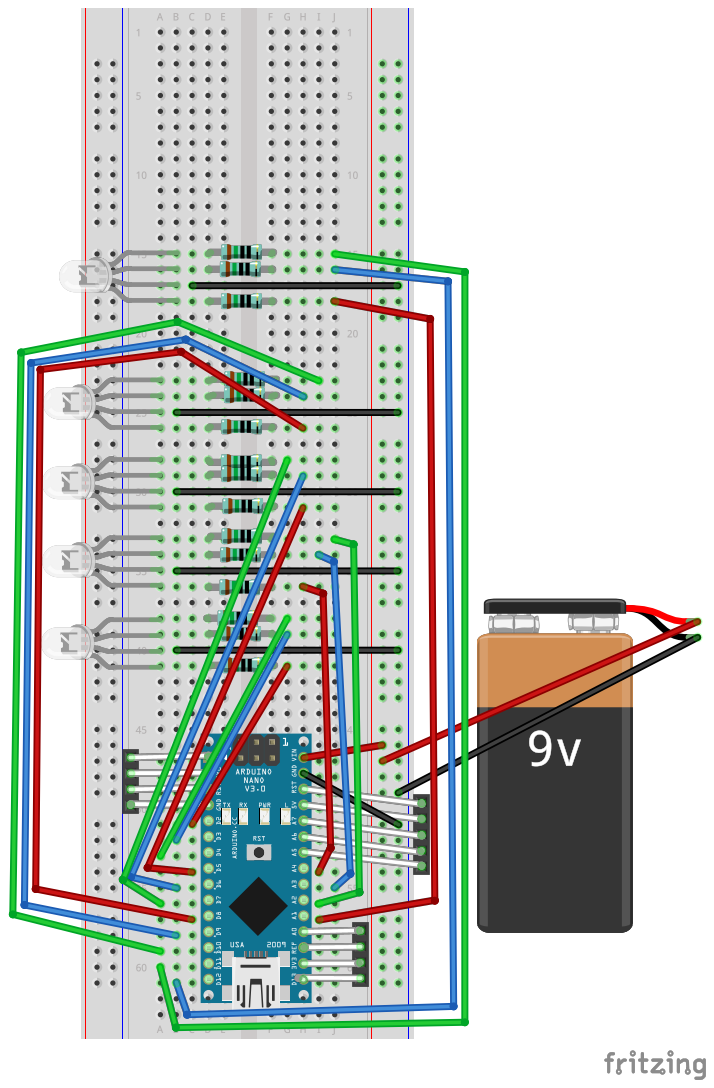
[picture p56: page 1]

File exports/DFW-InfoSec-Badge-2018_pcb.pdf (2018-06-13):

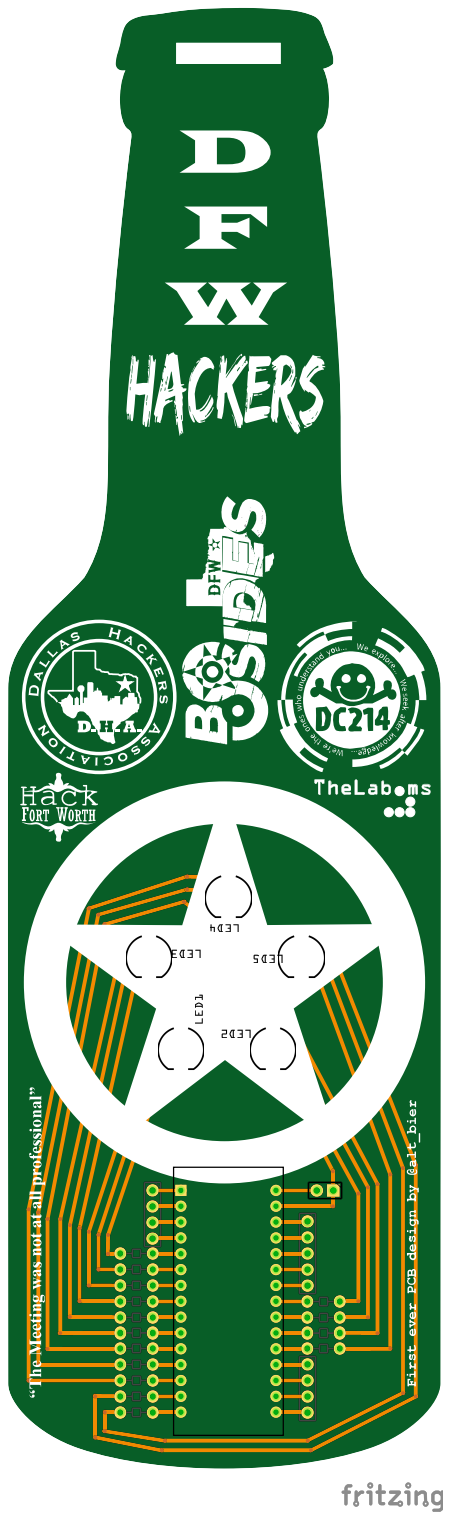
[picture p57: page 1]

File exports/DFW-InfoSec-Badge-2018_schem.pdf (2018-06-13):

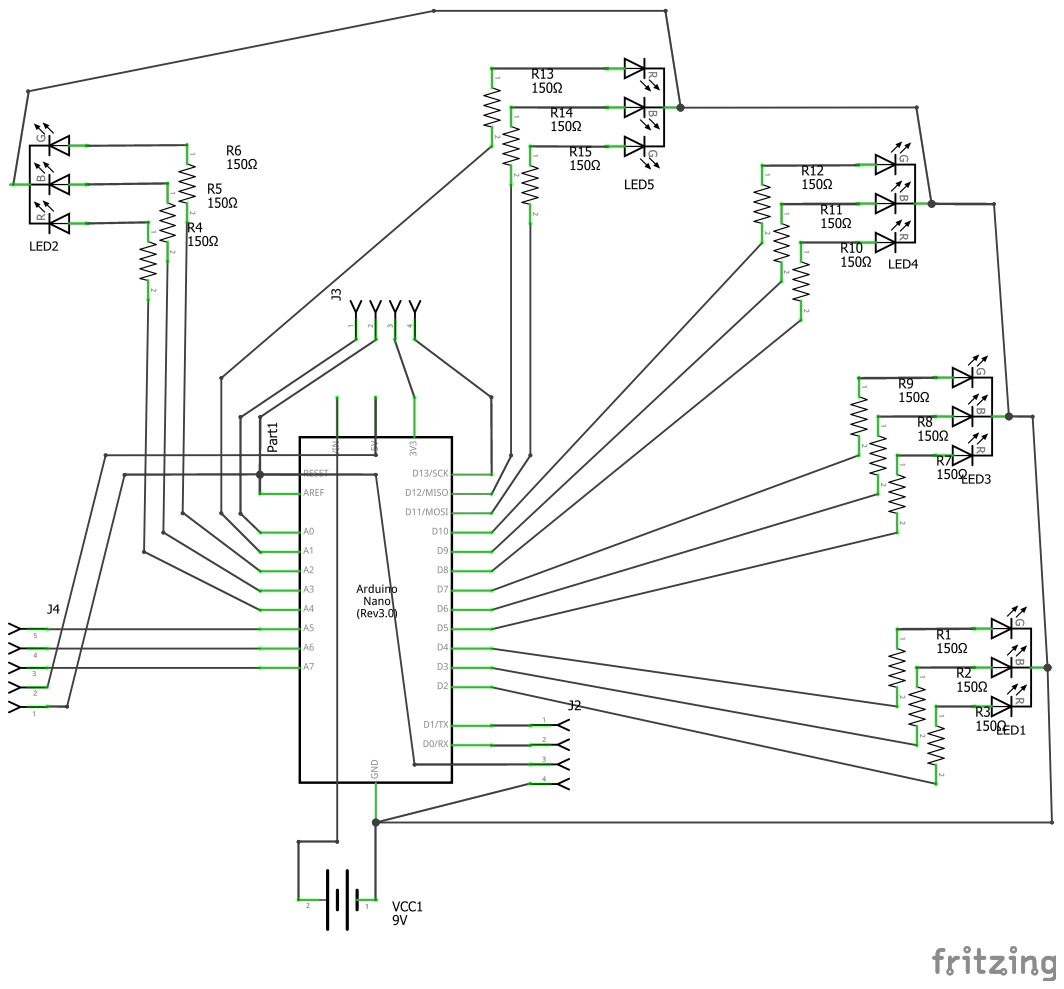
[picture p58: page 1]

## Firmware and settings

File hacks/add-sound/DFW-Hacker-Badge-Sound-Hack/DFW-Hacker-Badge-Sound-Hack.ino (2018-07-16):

/* **************************
 *  Sound Hack
 *  This hack requires an 8 ohm speaker be added to the badge
 *  This program will play sounds coordinated with LED lights
 *  The sound code was taken from this public domain code:
 *  http://www.arduino.cc/en/Tutorial/Tone
 * ************************** */

// Include some sound constants
#include "pitches.h"

// Define Pins
/*  NOTE that not all RGB LEDs have the same color pinout
 *  so you need to adjust these definitions based on
 *  the specific LEDs you use.
 *  Also confirm the SPEAKER positive pin connection
 *  (SPEAKER negative should go to ground)
 */
#define LED1_RED 2
#define LED1_GREEN 3
#define LED1_BLUE 4

#define LED2_RED 5
#define LED2_GREEN 6
#define LED2_BLUE 7

#define LED3_RED 8
#define LED3_GREEN 9
#define LED3_BLUE 10

#define LED4_RED 15
#define LED4_GREEN 12
#define LED4_BLUE 11

#define LED5_RED 18
#define LED5_GREEN 17
#define LED5_BLUE 16

#define SPEAKER 19

// LED Pin Array
int LED[5][3] = {
  {LED1_RED, LED1_GREEN, LED1_BLUE}, 
  {LED2_RED, LED2_GREEN, LED2_BLUE},
  {LED3_RED, LED3_GREEN, LED3_BLUE},
  {LED4_RED, LED4_GREEN, LED4_BLUE},
  {LED5_RED, LED5_GREEN, LED5_BLUE}
};

/*  Notes and durations and LED states of the melody to be played.
 *  Uncomment only one of each of the following for a specific melody: 
 *  numNotes, melodyNotes, noteDurations, and lightLeds
 *  numNotes = number of notes in the melody
 *  melodyNotes = notes that make up the melody from pitches.h constants
 *  noteDurations = 1 full note 2 half note 4 quarter note 8 eighth note...
 *  lightLeds = which LEDs to light for each note played, where each sub-element is
 *    an LED bitvector value 0=off, 1=red, 2=green, 4=blue (3=R&G 5=R&B 6=G&B 7=ALL)
 */

// basic test melody (shave and a haircut):
/*
int numNotes = 8;
int melodyNotes[8] = {
  NOTE_C4, NOTE_G3, NOTE_G3, NOTE_A3, NOTE_G3, 0, NOTE_B3, NOTE_C4
};
int noteDurations[8] = {
  4, 8, 8, 4, 4, 4, 4, 4
};
*/

// Deep In The Heart Of Texas :
int numNotes = 24;
int melodyNotes[24] = {
  NOTE_C3, NOTE_F3, NOTE_F3, NOTE_A3, 0, 
  NOTE_C3, NOTE_F3, NOTE_F3, NOTE_A3,
  NOTE_E4, 0, NOTE_E4, 0, 
  NOTE_E4, 0, NOTE_E4, 0, 
  NOTE_C4, NOTE_C4, NOTE_C4, NOTE_C4, NOTE_D4, 
  NOTE_A3, NOTE_G3
}; 
int noteDurations[24] = {
  5, 3, 3, 2, 16, 
  5, 3, 3, 4,
  32, 8, 32, 8, 
  32, 8, 32, 8,
  5, 6, 6, 3, 5, 
  4, 3
};
int lightLeds[24][5] = {
  {0, 4, 0, 4, 0}, {4, 0, 4, 0, 4}, {0, 4, 0, 4, 0}, {4, 0, 4, 0, 4}, {0, 0, 0, 0, 0},
  {0, 4, 0, 4, 0}, {4, 0, 4, 0, 4}, {0, 4, 0, 4, 0}, {4, 0, 4, 0, 4},
  {7, 7, 7, 7, 7}, {0, 0, 0, 0, 0}, {7, 7, 7, 7, 7}, {0, 0, 0, 0, 0}, 
  {7, 7, 7, 7, 7}, {0, 0, 0, 0, 0}, {7, 7, 7, 7, 7}, {0, 0, 0, 0, 0},
  {0, 4, 0, 4, 0}, {4, 0, 4, 0, 4}, {0, 4, 0, 4, 0}, {4, 0, 4, 0, 4}, {0, 4, 0, 4, 0}, 
  {4, 0, 4, 0, 4}, {0, 4, 0, 4, 0}
};


void setup() {
  // Initialize Pins As Output
  pinMode(LED1_RED, OUTPUT);
  pinMode(LED1_GREEN, OUTPUT);
  pinMode(LED1_BLUE, OUTPUT);
  
  pinMode(LED2_RED, OUTPUT);
  pinMode(LED2_GREEN, OUTPUT);
  pinMode(LED2_BLUE, OUTPUT);
  
  pinMode(LED3_RED, OUTPUT);
  pinMode(LED3_GREEN, OUTPUT);
  pinMode(LED3_BLUE, OUTPUT);
  
  pinMode(LED4_RED, OUTPUT);
  pinMode(LED4_GREEN, OUTPUT);
  pinMode(LED4_BLUE, OUTPUT);
  
  pinMode(LED5_RED, OUTPUT);
  pinMode(LED5_GREEN, OUTPUT);
  pinMode(LED5_BLUE, OUTPUT);

  pinMode(SPEAKER, OUTPUT);

  /*  Only playing sound one time in setup
   *  as that could get very annoying.
   *  
   *  The badge will continue the low power color walk code
   *  in the main loop after the initial sound/light show.
   *  
   *  The reset button on the Arduino can be used to play
   *  the sound again without fully power cycling the badge.
   *  
   *  sizeof(melodyNotes) not working
   */
  // iterate over the notes of the melody:
  for (int thisNote = 0; thisNote < numNotes; thisNote++) {
    // Light LEDs for this note
    for (int lednum=0; lednum < 5; lednum++) {
      switch (lightLeds[thisNote][lednum]) {
        case 7:
          digitalWrite(LED[lednum][0], HIGH); // R
          digitalWrite(LED[lednum][1], HIGH); // G
          digitalWrite(LED[lednum][2], HIGH); // B
          break;
        case 6:
          digitalWrite(LED[lednum][1], HIGH); // G
          digitalWrite(LED[lednum][2], HIGH); // B
          break;
        case 5:
          digitalWrite(LED[lednum][0], HIGH); // R
          digitalWrite(LED[lednum][2], HIGH); // B
          break;
        case 4:
          digitalWrite(LED[lednum][2], HIGH); // B
          break;
        case 3:
          digitalWrite(LED[lednum][0], HIGH); // R
          digitalWrite(LED[lednum][1], HIGH); // G
          break;
        case 2:
          digitalWrite(LED[lednum][1], HIGH); // G
          break;
        case 1:
          digitalWrite(LED[lednum][0], HIGH); // R
          break;
        default:
          // 0 or other = don't turn any on
          break;
      }
    }

    // to calculate the note duration, take one second divided by the note type.
    //e.g. quarter note = 1000 / 4, eighth note = 1000/8, etc.
    int noteDuration = 1000 / noteDurations[thisNote];
    tone(SPEAKER, melodyNotes[thisNote], noteDuration);

    // to distinguish the notes, set a minimum time between them.
    // the note's duration + 30% seems to work well:
    int pauseBetweenNotes = noteDuration * 1.30;
    delay(pauseBetweenNotes);
    
    // stop the tone playing:
    noTone(SPEAKER);

    // Turn Off All LEDs
    alloff();
  }
}

// Main Loop
void loop() {
  
  /*   This is the same code from the low power color walk program
   *   that will be looped until a power cycle or reset plays the sounds again. 
   */
  
  // Set Delay for each transition [in ms]
  int DelayTime = 150;

  // Color Order in R,G,B Binary Values
  // White OFF Red OFF 
  // Yellow OFF Green OFF 
  // Cyan OFF Blue OFF
  // Magenta OFF
  char Color[14][3] = {
    {1, 1, 1}, {0, 0, 0}, {1, 0, 0}, {0, 0, 0}, 
    {1, 1, 0}, {0, 0, 0}, {0, 1, 0}, {0, 0, 0}, 
    {0, 1, 1}, {0, 0, 0}, {0, 0, 1}, {0, 0, 0}, 
    {1, 0, 1}, {0, 0, 0}
  };

  for (int c = 0; c < 14; c++) {               // Color Loop (MAX = Color[n])
      for (int l = 0; l < 5; l++) {           // LEDs (MAX = LED[n])
        alloff();                             // Turn All Off Before Turning on Next LED
        for (int i = 0; i < 3; i++) {         // Individual Colors (MAX = 3 rgb)
          digitalWrite(LED[l][i], Color[c][i]); 
        }
        delay(DelayTime);
      }
  }
}

// All Off Loop
void alloff()
{
      for (int l = 0; l < 5; l++) {           // LEDs (MAX = LED[n])
        for (int i = 0; i < 3; i++) {         // Individual Colors (MAX = 3 rgb)
          digitalWrite(LED[l][i], LOW); 
        }
      }
}

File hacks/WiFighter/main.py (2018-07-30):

import board
import busio
import neopixel
from time import sleep
pixels = neopixel.NeoPixel(board.NEOPIXEL, 10, brightness=.01)
uart = busio.UART(board.TX, board.RX, baudrate=115200)
data = uart.read(2)
while True:
    data = uart.read(2)
    if data is not None:
        data_string = ''.join([chr(b) for b in data])
        print(data_string, end="")

        count = int(data_string)
        if count <= 9:
            for x in range(count):
                pixels[x] = (255, 0, 0)
                sleep(.05)
            pixels[count] = (0, 255, 0)
        else:
            for x in range(count % 10):
                pixels[x] = (255, 0, 0)
                sleep(.05)
            pixels[count % 10] = (0, 0, 255)
            count = count % 10
        for x in range(count - 1, -1, -1):
            pixels[x] = (0, 0, 0)
            sleep(.05)
        sleep(.75)
        pixels.fill((0, 0, 0))

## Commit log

2018-06-18 Updated info on the Arduino Nano CH340 driver requirements.
2018-06-19 PCB Design Corrections and Financials Breakdown
    [DFW-InfoSec-Badge-2018.fzz]
2018-06-19 Minor corrections complete. Gerber export for production.
    [DFW-InfoSec-Badge-2018.fzz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]
2018-06-23 Updated financials and wrote a new low power program for coin cells
2018-07-02 Added Assembly Instructions
2018-07-22 Add files via upload
    Converted the project to use PL9823 Addressable LED devices
